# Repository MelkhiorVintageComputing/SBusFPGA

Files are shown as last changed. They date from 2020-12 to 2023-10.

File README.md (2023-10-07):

# A FPGA on a SBus card...

## Goal

The goal of this repository is to be able to interface a modern (2020 era) [FPGA](https://en.wikipedia.org/wiki/Field-programmable_gate_array) with a [SBus](https://en.wikipedia.org/wiki/SBus) host. SBus was widely used in SPARCstation and compatibles system in the first half of the 90s. It was progressively displaced by PCI from the mid-90s onward, and is thoroughly obsolete.

So unless you're a retrocomputing enthusiast with such a machine, this is useless. To be honest, even if you are such an enthusiast, it's probably not that useful...

I'm a software guy and know next to nothing about hardware design, so this is very much a work-in-progress and is likely full of rookie mistakes.

To save on PCB cost, the board is smaller than a 'true' SBus board; the hardware directory includes an OpenSCAD 3D-printable extension to make the board compliant to the form factor (visible in the pictures in 'Pictures') (need to be updated for V1.3).

## Current status

2023-10-07: V1.3 in testing.

2022-11-18: V1.2 seems stable, with various subsets of the peripherals described below. It only lacks a proper video output, such as the one available in the [NuBusFPGA](https://github.com/rdolbeau/NuBusFPGA). Unfortunately the FPGA board used in V1.0/V1.2 (ZTex 2.13) doesn't have enough available I/O to add it in addition to the already existing I/Os.

## The hardware

Directory 'sbus-to-ztex'

The V1.2 custom board is a SBus-compliant (I hope...) board, designed to receive a [ZTex USB-FPGA Module 2.13](https://www.ztex.de/usb-fpga-2/usb-fpga-2.13.e.html) as a daughterboard. The ZTex module contains the actual FPGA (Artix-7), some RAM, programming hardware, etc. The SBus board contains level-shifters ICs to interface between the SBus signals and the FPGA, a serial header, a Led, a JTAG header, a micro-sd card slot, a USB micro-B connector, and a (Pmod)[https://digilent.com/shop/boards-and-components/system-board-expansion-modules/pmods/] connector. It supports every SBus feature except the optional parity (i.e. it can do both slave and master modes) and interrupt level 1 to 6 are connected.

The V1.3 custom board is similar to V1.2 but reorganized & redesigned to have all components on the top side and cleaner routing. It also loose the led, setial header & micro-sd to gain a HDMI connector. The USB micro-B is still present, and the PMod was rewired to carry 8 length-matched differential pairs.

The PCB was designed with Kicad 5.0 for V1.2, 5.1 for V1.3.

## The gateware (Migen)

Directory 'sbus-to-ztex-gateware-migen'

### Intro

The gateware is written in the Migen language, choosen because that's what [Litex](https://github.com/enjoy-digital/litex/) uses.
It implements a simple CPU-less Litex SoC built around a Wishbone bus, with a custom bridge between the SBus and the Wishbone.

A ROM, a SDRAM controller ([litedram](https://github.com/enjoy-digital/litedram) to the on-board DDR3), a TRNG (using the [NeoRV32](https://github.com/stnolting/neorv32) TRNG), an USB OHCI (host controller, using the Litex wrapper around the [SpinalHDL](https://github.com/SpinalHDL/SpinalHDL) implementation), a Curve25519 Crypto Engine (taken from the [Betrusted.IO](https://betrusted.io/) project and expanded to add AES and GCM support) and a Litex micro-sd controller can be connected to that bus. As a test feature for the Pmod connector, a bw2/cg3/cg6-compatible framebuffer can be implemented using a custom RGA222 VGA Pmod (with serious color quality restrictions). The 'Goblin' framebuffer (a multi-depth gramebuffer) can also be used with the VGA Pmod, using 8-bits depth in the console or accelerated 24-bits in X11. Alternatively on the Pmod en I2C bus (the Betrusted.IO wrapper around an OpenCore controller) can be implemented for e.g. temperature control.

### Details

Master access to the SBus by the host are routed to the Wishbone to access the various CSRs / control registers of the devices.

The ROM exposes the devices' existence and specifications to the host, initializes the embedded SDRAM controller (but assuming known values, the NetBSD driver can also optionally initialize the SDRAM via proper calibration), enables FB support on the bw2/cg3/cg6 (last one with accelerated scrolling), and has support for RO access to the sdcard such enabling booting.

The USB OHCI DMA (USB 1.1) is bridged from the Wishbone to the SBus by having the physical addresses of the Wishbone (that match the virtual addresses from NetBSD DVMA allocations) to the bridge (see also 'Sun4m vs. Sun4c' below). Reads are buffered by block of 16 bytes; currently writes are unbuffered (and somewhat slow, as they need a full SBus master cycle for every transaction of 32 bits or less). The standard NetBSD OHCI driver is used, with just a small custom SBus-OHCI driver mirroring the PCI-OHCI one. It uses the interrupt level 4 by default. It connects to the micro-B USB connector, an a cable such as [this one](https://www.startech.com/en-us/cables/uusbotgra) allows to expose a conventional USB type A connector for either an external (preferably self-powered) USB Hub or a single low-power device.

The SDRAM has its own custom DMA controller, using native Litedram interface to the memory, and some FIFO to/from the SBus. A custom NetBSD driver exposes it as a drive on which you can swap. It's also usable as a 'fast', volatile disk (for e.g. /tmp or similar temporary filesystem). It can use a interrupt line, but software support isn't there yet (only synchronous polling).

The micro-sd card controller is using a similar driver to the SDRAM, so is also currently limited to sychronous polling and lack of support for interrupts (or removability). It also has some level of support in the PROM, enabling it as a boot device (of course using a NetBSD kernel with appropriate support). For its DMA engine, the micro-sd controller uses the same Wishbone/SBus bridge as designed for the USB OHCI.

The TRNG has a NetBSD driver to add entropy to the entropy pool.

The Curve25519 Engine currently exposes an IOCTL to do the computation, which has yet to be integrated usefully in e.g. OpenSSL. It could use a interrupt line, but it's not yet implemented in software. The load/store unit used the same Wishbone/SBus bridge as designed for the USB OHCI.

The I2C bus currently uses a custom Pmod to plug an AT30TS74 temperature sensor (LM75-compatible, usable with 'envstat' in NetBSD), but should support most/all I2C devices supported by NetBSD.

The bw2/cg3/cg6 emulation requires the custom Pmod on V1.2, and colors are vert limited at 2 bits per channel, so it's for testing mostly. V1.3 has a HDMI connector using DVI signaling and so support the full color range. bw2/cg3 can work as a PROM console, a NetBSD console, and with X11, all as an non-accelerated framebuffer. Resolution can be arbitrary but is fixed in the bitstream at synthesis time, the current design can go up to 1920x1080@60Hz. cg6 emulation is similar but uses a micro-coded VexRiscv core to emulate some of the cg6 hardware acceleration, enough to accelerate the PROM console, the NetBSD console and X11 EXA acceleration in NetBSD 9.0. The cg3/cg6 emulation was also tested with the original PROM code for cg3 (501-1415) and TGX+ (501-2253), but this requires hardware-based initialization (instead of PROM-based) and prevent exposing other devices in the PROM code.

The 'Goblin' framebuffer works similarly to the cg6 emulation (from which it has grown for the NuBusFPGA), but is using 24-bits in X11 (switching in a way similar to the cg14) and has some Xrender acceleration. Using the same 2-bits-per-channel VGA Pmod, it also suffers from color limitations ob V1.2. It also uses tje HDMI connector on V1.3.

### Special Notes

Currently the design uses a Wishbone Crossbar Interconnect from Litex instead of a Shared Interconnect, as for some reason using a Shared Interconnect causes issues between devices (disabling the USB OHCI seem also to solve the issue, it generates a lot of cycles on the buses). I might be misusing Wishbone. With the Crossbar, all devices are usable simultaneously if they fit in the FPGA.

As not everything lives in the same clock domain, the design also use a Wishbone CDC, a wrapper around the one from [Verilog Wishbone Components](https://github.com/alexforencich/verilog-wishbone).

## The software

Directory 'NetBSD'

Some basic drivers for NetBSD 9.0/sparc to enable the devices as described above. bw2/cg3/cg6 uses unmodifed NetBSD drivers. USB OHCI needs only a SBus-OHCI layer, the NetBSD OHCI driver and USB stack are used unmodified.

## Sun4m vs. Sun4c

The current DMA scheme for Wishbone devices (USB OHCI, micro-sd, ...) works fine on sun4m machine with an IOMMU (SPARCstation 4, 5, 10, 20 ...). NetBSD will always allocate the DVMA buffers in the range from IOMMU_DVMA_BASE to the end of the memory space (IOMMU_DVMA_BASE is 0xFC000000 by default, and that must include 0xFF000000 to the end which are the only virtual addresses accessible by some legacy devices used in some SPARCstation). However, sun4c machine (SPARCstation 1, 2, IPC, IPX, ...) do not have an IOMMU, and have no virtual address restriction for non-legacy device. And the NetBSD kernel takes advantage of this, I have observed DVMA buffers mapped to prefix 0xF4 and 0xF3. Extending the mapping for the DVMA bridge in Wishbone to the full 0xF prefix enable booting from sd-card on an IPX, but I'm not sure this is reliable.

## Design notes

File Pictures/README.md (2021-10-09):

## Some picture of the V1.0 and V1.2 boards

This is V1.2:
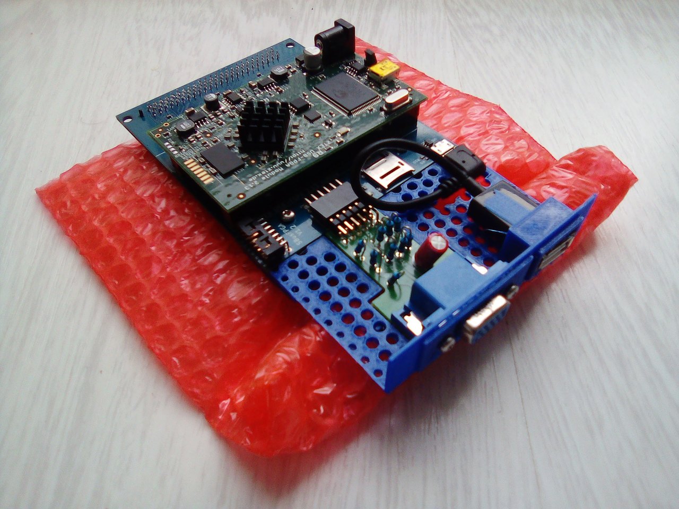
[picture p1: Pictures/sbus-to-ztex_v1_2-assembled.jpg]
Picture of the V1.2 board with cables


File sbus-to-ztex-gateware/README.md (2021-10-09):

## Current status

2021-03-21: The adapter board seems to work fine in two different SS20. Currently the embedded PROM code exposes three devices in the FPGA:

* "RDOL,cryptoengine": exposes a (way too large) polynomial multiplier to implement GCM mode and a AES block. Currently used to implement DMA-based acceleration of AES-256-CBC through /dev/crypto. Unfortunately OpenSSL doesn't support AES-256-GCM in the cryptodev engine, and disagree with NetBSD's /dev/crypto on how to implement AES-256-CTR. And the default SSH cannot use cryptodev, it closes all file descriptors after cryptodev has opened /dev/crypto... still WiP.

* "RDOL,trng": exposes a 5 MHz counter (didn't realize the SS20 already had a good counter) and a so-far-not-true TRNG (implemented by a PRNG). The 'true' random generators I've found make Vivado screams very loudly when synthesizing... anyway both works fine in NetBSD 9.0 as a timecounter and an entropy source (which a PRNG really isn't, I know).  still WiP.

* "RDOL,sdcard": trying to expose the micro-sd card slot as a storage device, at first using SPI mode. So far reading seems to work, and NetBSD can see a Sun disklabel on the micro-sd card if it has been partitioned that way. Mounting a FAT filesystem read-only now works (with very little testing as of yet). Writing not working yet. Very much WiP.

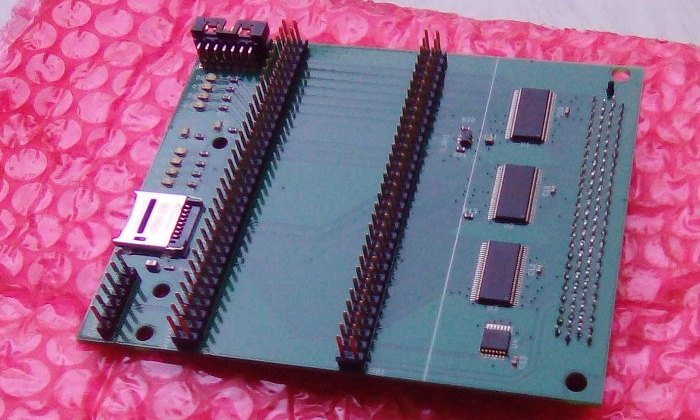
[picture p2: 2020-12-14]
Pictures/sbus-to-ztex.jpg

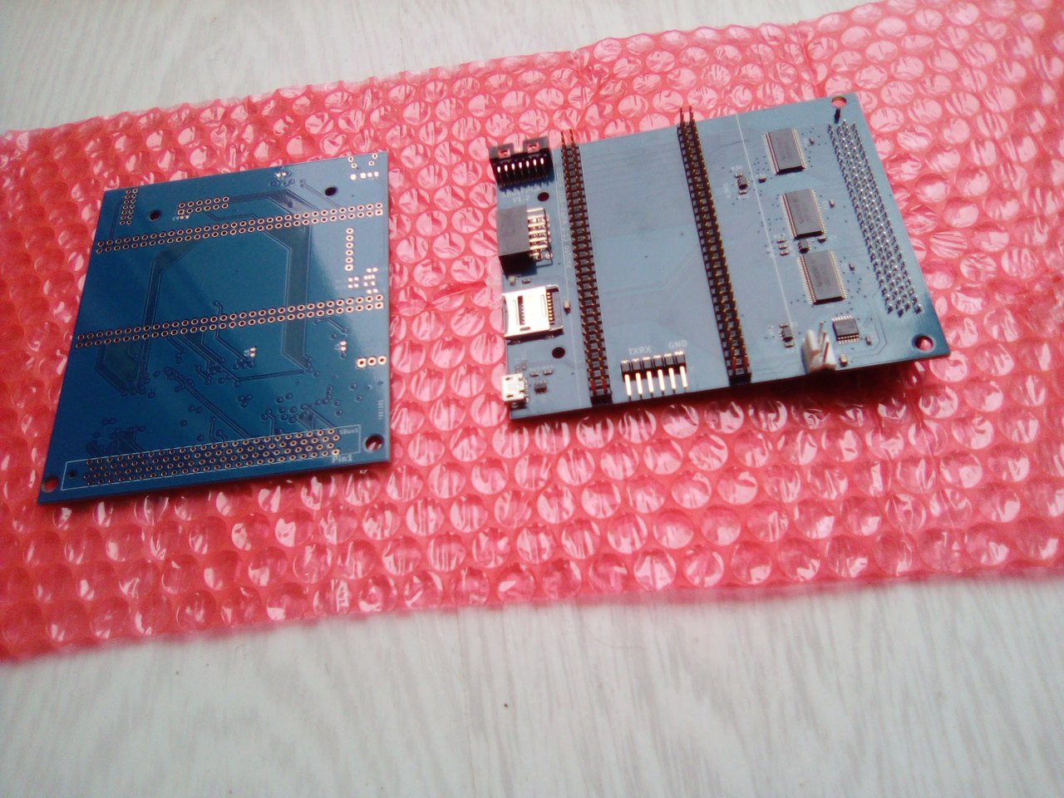
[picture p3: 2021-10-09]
Pictures/sbus-to-ztex_v1_2.jpg

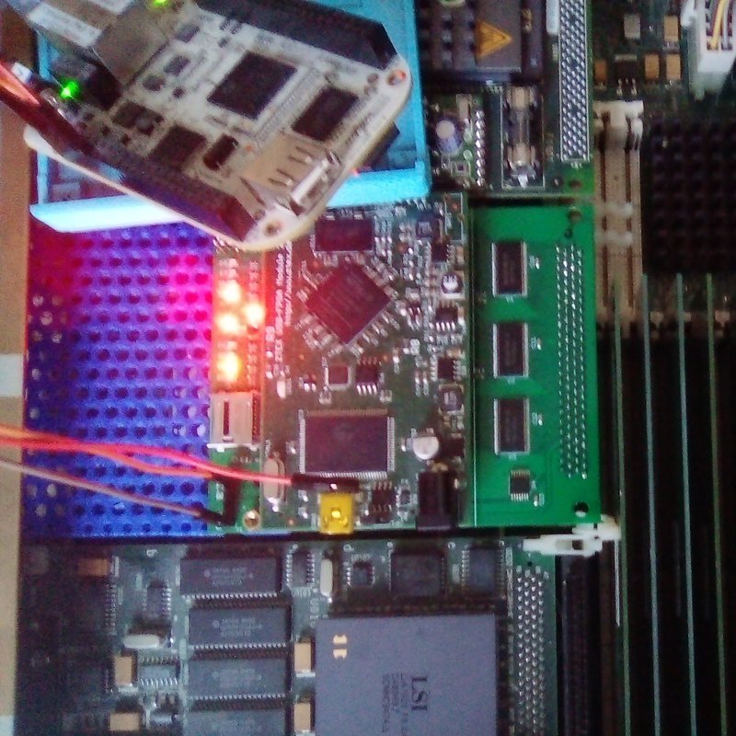
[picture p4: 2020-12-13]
Pictures/sbus-to-ztex-in-SS20.jpg

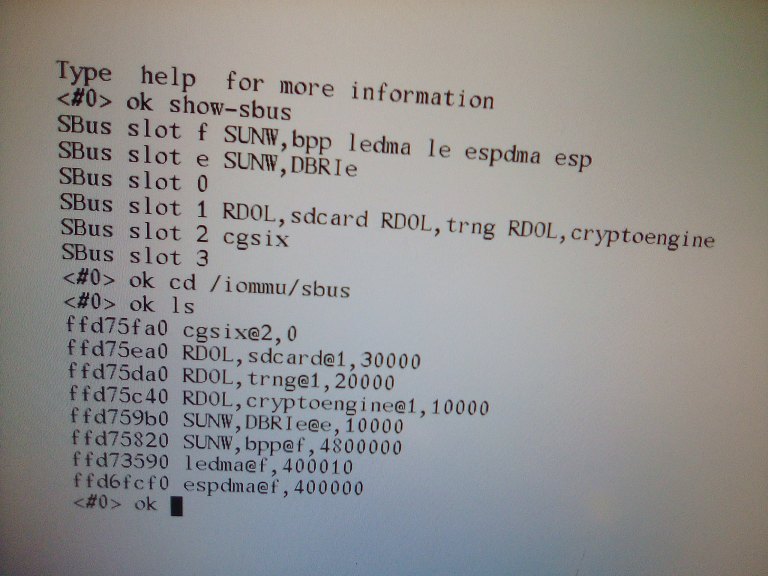
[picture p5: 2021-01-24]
Pictures/sbus-to-ztex-prom.jpg

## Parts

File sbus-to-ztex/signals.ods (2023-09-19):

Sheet: length
signal | pin (FPGA) | pin (board) | Ztex 2.13 | Current | Total | Missing | Should be
HDMI_D2+ |  | D04 | 47,25 | 26,005 | 73,255 | 0 | 26,005
HDMI_D2- |  | D05 | 44,17 | 29,085 | 73,255 | 0 | 29,085
HDMI_D1+ |  | D06 | 47,7 | 25,555 | 73,255 | 0 | 25,555
HDMI_D1- |  | D07 | 40,07 | 33,185 | 73,255 | 0 | 33,185
HDMI_D0+ |  | D08 | 43,24 | 30,015 | 73,255 | 0 | 30,015
HDMI_D0- |  | D09 | 36,91 | 36,345 | 73,255 | 0 | 36,345
HDMI_CLK+ |  | D10 | 36,12 | 37,135 | 73,255 | 0 | 37,135
HDMI_CLK- |  | D11 | 31,28 | 41,975 | 73,255 | 0 | 41,975
 |  |  |  |  | 73,255
PMOD-1112+ |  | D21 | 14,73 | 20,876 | 35,606 | 0 | 20,876 | -1,11
PMOD-1112- |  | D22 | 13,62 | 21,986 | 35,606 | 0 | 21,986
PMOD-910- |  | D23 | 11,52 | 24,086 | 35,606 | 0 | 24,086 | 1,39
PMOD-910+ |  | D24 | 12,91 | 22,696 | 35,606 | 0 | 22,696
PMOD-78- |  | D25 | 14,18 | 21,426 | 35,606 | 0 | 21,426 | 1,788
PMOD-78+ |  | D26 | 15,93 | 19,638 | 35,568 | 0,038000000000004 | 19,676
PMOD-56+ |  | D27 | 17,29 | 18,316 | 35,606 | 0 | 18,316 | 1,06
PMOD-56- |  | D28 | 18,35 | 17,256 | 35,606 | 0 | 17,256
 |  |  |  |  | 35,606

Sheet: 2.13 pin -> trace length
A03 | 47,94
A04 | 50,82
A05 | 49,92
A06 | 46,16
A07 | 41,01
A08 | 36,34
A09 | 35,18
A10 | 31,47
A11 | 29,79
A12 | 28,44
A13 | 25,47
A14 | 33,51
A18 | 19,12
A19 | 16,11
A20 | 12,52
A21 | 11,42
A22 | 16,17
A23 | 12,65
A24 | 16,68
A25 | 18,84
A26 | 14,67
A27 | 17,14
A28 | 22,76
A29 | 23,12
A30 | 26,67
B03 | 47,46
B04 | 43,6
B05 | 50,53
B06 | 43,56
B07 | 41,18
B08 | 38,13
B09 | 33,55
B10 | 30,82
B11 | 42,85
B12 | 26,76
B13 | 23,54
B14 | 21,66
B18 | 12,94
B19 | 10,5
B20 | 7,79
B21 | 4,99
B22 | 7,67
B23 | 6,56
B24 | 9,37
B25 | 11,32
B26 | 10,64
B27 | 14,66
B28 | 16,13
B29 | 18,45
B30 | 19,53
C03 | 48,06
C04 | 50,42
C05 | 44,03
C06 | 40,65
C07 | 40,55
C08 | 36,89
C09 | 42,83
C10 | 40,83
C11 | 29,53
C12 | 28,85
C13 | 23,26
C14 | 22,23
C15 | 29,19
C19 | 15,66
C20 | 13,54
C21 | 13,92
C22 | 10,82
C23 | 8,85
C24 | 10,26
C25 | 10,34
C26 | 10,91
C27 | 15,81
C28 | 16,75
C29 | 18,52
C30 | 20,19
D03 | 48,26
D04 | 47,25
D05 | 44,17
D06 | 47,7
D07 | 40,07
D08 | 43,24
D09 | 36,91
D10 | 36,12
D11 | 31,28
D12 | 28,32
D13 | 27,1
D14 | 24,45
D15 | 23,76
D19 | 19,51
D20 | 17,59
D21 | 14,73
D22 | 13,62
D23 | 11,52
D24 | 12,91
D25 | 14,18
D26 | 15,93
D27 | 17,29
D28 | 18,35
D29 | 20,28
D30 | 22,14

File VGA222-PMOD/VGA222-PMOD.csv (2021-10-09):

Part/Designator | Manufacture Part Number/Seeed SKU | Quantity | URL
C3 | 860021373002 | 1
J2 | A2541WR-2x6P | 1
J1 | L77HDE15SD1CH4RHNVGA | 1 | https://www.mouser.fr/ProductDetail/Amphenol-Commercial-Products/L77HDE15SD1CH4RHNVGA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
R10,R11 | MFR-25FBF52-100R | 2
R13,R19,R25 | MFR-25FBF52-1K | 3
R12,R18,R24 | MFR-25FTE52-510R | 3
R9 | MFR50SFTE52-1M | 1 | https://www.lcsc.com/product-detail/Chip-Resistor-Surface-Mount_UNI-ROYAL-Uniroyal-Elec-AS03W4J0105T5E_C966202.html

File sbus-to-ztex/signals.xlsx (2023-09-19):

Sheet: Summary
Connector PIN | USB-FPGA-Module 2.13 |  |  |  |  |  |  |  |  |  |  |  |  |  |  |  |  |  |  |  |  |  |  | LITEX def
 | Signal | I/O Voltage | FPGA PIN | CPLD PIN | Notes | Number |  | Used Pin | Signal | 2.13 trace length (mm) | added length |  |  |  |  |  |  | XDC PIN | XDC TIMING IN | DXC TIMING OUT |  | https://forums.xilinx.com/t5/Timing-Analysis/Significance-of-set-output-delay-max-min-negative-and-positive/td-p/779277
A1 | VIN |  |  |  | 4.5..16V | 1 | #N/A
B1 | VIN |  |  |  | 4.5..16V | 2 | #N/A |  |  |  |  |  |  |  |  |  |  | TIS (min) | 15 | 20 | TOD (max) | 22.5 in B0
A2 | GND |  |  |  |  | 3 | #N/A |  |  |  |  |  |  |  |  |  | 0 in B0 | TIH (min) | 1 | 2.5 | TOH (min) |  | 0.6304662693
B2 | GND |  |  |  |  | 4 | #N/A |  |  |  |  |  |  |  |  |  |  |  | mm/ns (fast so MIN) | mm/ns (slow so MAX) |  |  | 0.2218339054
 |  |  |  |  |  |  | #N/A |  |  |  |  |  |  |  |  |  |  |  | 200 | 150
A3 | K16~IO_25_15 | VCCO_AB | K16 |  |  | 5 | SBUS_3V3_BR* | K16~IO_25_15 | SBUS_3V3_BR* | 47.94 | 78.15 |  | 126.09 | 4.96 |  | -81.73 | IO | set_property PACKAGE_PIN K16 [get_ports {SBUS_3V3_BR*}] set_property IOSTANDARD LVTTL [get_ports {SBUS_3V3_BR*}] | set_input_delay -clock SBUS_3V3_CLK -min 1,159 [get_ports {SBUS_3V3_BR*}] set_input_delay -clock SBUS_3V3_CLK -max 25,795 [get_ports {SBUS_3V3_BR*}] | set_output_delay -clock SBUS_3V3_CLK -min -1,648 [get_ports {SBUS_3V3_BR*}] set_output_delay -clock SBUS_3V3_CLK -max 21,636 [get_ports {SBUS_3V3_BR*}] |  | set_input_delay -clock SBUS_3V3_CLK -min 1,159 [get_ports {SBUS_3V3_BR*}] set_input_delay -clock SBUS_3V3_CLK -max 25,795 [get_ports {SBUS_3V3_BR*}] set_output_delay -clock SBUS_3V3_CLK -min -1,648 [get_ports {SBUS_3V3_BR*}] set_output_delay -clock SBUS_3V3_CLK -max 21,636 [get_ports {SBUS_3V3_BR*}]
B3 | J18~IO_L23N_T3_FWE_B_15 | VCCO_AB | J18 |  |  | 6 | I2C0_SDA | J18~IO_L23N_T3_FWE_B_15 | I2C0_SDA | 47.46 | #N/A |  | #N/A | #N/A |  | #N/A | IO | set_property PACKAGE_PIN J18 [get_ports {I2C0_SDA}] set_property IOSTANDARD LVTTL [get_ports {I2C0_SDA}]
A4 | K15~IO_L24P_T3_RS1_15 | VCCO_AB | K15 |  |  | 7 | SBUS_3V3_BG* | K15~IO_L24P_T3_RS1_15 | SBUS_3V3_BG* | 50.82 | 77.84 |  | 128.66 | 5.07 |  | -84.29 | IO | set_property PACKAGE_PIN K15 [get_ports {SBUS_3V3_BG*}] set_property IOSTANDARD LVTTL [get_ports {SBUS_3V3_BG*}] | set_input_delay -clock SBUS_3V3_CLK -min 1,171 [get_ports {SBUS_3V3_BG*}] set_input_delay -clock SBUS_3V3_CLK -max 25,812 [get_ports {SBUS_3V3_BG*}] | set_output_delay -clock SBUS_3V3_CLK -min -1,635 [get_ports {SBUS_3V3_BG*}] set_output_delay -clock SBUS_3V3_CLK -max 21,654 [get_ports {SBUS_3V3_BG*}] |  | set_input_delay -clock SBUS_3V3_CLK -min 1,171 [get_ports {SBUS_3V3_BG*}] set_input_delay -clock SBUS_3V3_CLK -max 25,812 [get_ports {SBUS_3V3_BG*}] set_output_delay -clock SBUS_3V3_CLK -min -1,635 [get_ports {SBUS_3V3_BG*}] set_output_delay -clock SBUS_3V3_CLK -max 21,654 [get_ports {SBUS_3V3_BG*}]
B4 | J17~IO_L23P_T3_FOE_B_15 | VCCO_AB | J17 |  |  | 8 | I2C0_SCL | J17~IO_L23P_T3_FOE_B_15 | I2C0_SCL | 43.6 | #N/A |  | #N/A | #N/A |  | #N/A | IO | set_property PACKAGE_PIN J17 [get_ports {I2C0_SCL}] set_property IOSTANDARD LVTTL [get_ports {I2C0_SCL}]
A5 | J15~IO_L24N_T3_RS0_15 | VCCO_AB | J15 |  |  | 9 | SBUS_3V3_AS* | J15~IO_L24N_T3_RS0_15 | SBUS_3V3_AS* | 49.92 | 67.60 |  | 117.52 | 4.63 |  | -73.15 | IO | set_property PACKAGE_PIN J15 [get_ports {SBUS_3V3_AS*}] set_property IOSTANDARD LVTTL [get_ports {SBUS_3V3_AS*}] | set_input_delay -clock SBUS_3V3_CLK -min 1,116 [get_ports {SBUS_3V3_AS*}] set_input_delay -clock SBUS_3V3_CLK -max 25,738 [get_ports {SBUS_3V3_AS*}] | set_output_delay -clock SBUS_3V3_CLK -min -1,691 [get_ports {SBUS_3V3_AS*}] set_output_delay -clock SBUS_3V3_CLK -max 21,579 [get_ports {SBUS_3V3_AS*}] |  | set_input_delay -clock SBUS_3V3_CLK -min 1,116 [get_ports {SBUS_3V3_AS*}] set_input_delay -clock SBUS_3V3_CLK -max 25,738 [get_ports {SBUS_3V3_AS*}] set_output_delay -clock SBUS_3V3_CLK -min -1,691 [get_ports {SBUS_3V3_AS*}] set_output_delay -clock SBUS_3V3_CLK -max 21,579 [get_ports {SBUS_3V3_AS*}]
B5 | K13~IO_L17P_T2_A26_15 | VCCO_AB | K13 |  |  | 10 | SBUS_OE | K13~IO_L17P_T2_A26_15 | SBUS_OE | 50.53 | #N/A |  | #N/A | #N/A |  | #N/A | IO | set_property PACKAGE_PIN K13 [get_ports {SBUS_OE}] set_property IOSTANDARD LVTTL [get_ports {SBUS_OE}]
A6 | H15~IO_L19N_T3_A21_VREF_15 | VCCO_AB | H15 |  | VREF Bank 15 | 11 | SBUS_3V3_SEL* | H15~IO_L19N_T3_A21_VREF_15 | SBUS_3V3_SEL* | 46.16 | 74.37 |  | 120.53 | 4.75 |  | -76.16 | O | set_property PACKAGE_PIN H15 [get_ports {SBUS_3V3_SEL*}] set_property IOSTANDARD LVTTL [get_ports {SBUS_3V3_SEL*}] | set_input_delay -clock SBUS_3V3_CLK -min 1,131 [get_ports {SBUS_3V3_SEL*}] set_input_delay -clock SBUS_3V3_CLK -max 25,758 [get_ports {SBUS_3V3_SEL*}] | set_output_delay -clock SBUS_3V3_CLK -min -1,676 [get_ports {SBUS_3V3_SEL*}] set_output_delay -clock SBUS_3V3_CLK -max 21,599 [get_ports {SBUS_3V3_SEL*}] |  | set_output_delay -clock SBUS_3V3_CLK -min -1,676 [get_ports {SBUS_3V3_SEL*}] set_output_delay -clock SBUS_3V3_CLK -max 21,599 [get_ports {SBUS_3V3_SEL*}]
B6 | J13~IO_L17N_T2_A25_15 | VCCO_AB | J13 |  |  | 12 | SBUS_3V3_D[00] | J13~IO_L17N_T2_A25_15 | SBUS_3V3_D[00] | 43.56 | 44.69 |  | 88.25 | 3.47 |  | -43.88 | IO | set_property PACKAGE_PIN J13 [get_ports {SBUS_3V3_D[00]}] set_property IOSTANDARD LVTTL [get_ports {SBUS_3V3_D[00]}] | set_input_delay -clock SBUS_3V3_CLK -min 0,969 [get_ports {SBUS_3V3_D[00]}] set_input_delay -clock SBUS_3V3_CLK -max 25,543 [get_ports {SBUS_3V3_D[00]}] | set_output_delay -clock SBUS_3V3_CLK -min -1,837 [get_ports {SBUS_3V3_D[00]}] set_output_delay -clock SBUS_3V3_CLK -max 21,384 [get_ports {SBUS_3V3_D[00]}] |  | set_input_delay -clock SBUS_3V3_CLK -min 0,969 [get_ports {SBUS_3V3_D[00]}] set_input_delay -clock SBUS_3V3_CLK -max 25,543 [get_ports {SBUS_3V3_D[00]}] set_output_delay -clock SBUS_3V3_CLK -min -1,837 [get_ports {SBUS_3V3_D[00]}] set_output_delay -clock SBUS_3V3_CLK -max 21,384 [get_ports {SBUS_3V3_D[00]}]
A7 | J14~IO_L19P_T3_A22_15 | VCCO_AB | J14 |  |  | 13 | SBUS_3V3_D[02] | J14~IO_L19P_T3_A22_15 | SBUS_3V3_D[02] | 41.01 | 41.44 |  | 82.45 | 3.25 |  | -38.08 | IO | set_property PACKAGE_PIN J14 [get_ports {SBUS_3V3_D[02]}] set_property IOSTANDARD LVTTL [get_ports {SBUS_3V3_D[02]}] | set_input_delay -clock SBUS_3V3_CLK -min 0,940 [get_ports {SBUS_3V3_D[02]}] set_input_delay -clock SBUS_3V3_CLK -max 25,504 [get_ports {SBUS_3V3_D[02]}] | set_output_delay -clock SBUS_3V3_CLK -min -1,866 [get_ports {SBUS_3V3_D[02]}] set_output_delay -clock SBUS_3V3_CLK -max 21,345 [get_ports {SBUS_3V3_D[02]}] |  | set_input_delay -clock SBUS_3V3_CLK -min 0,940 [get_ports {SBUS_3V3_D[02]}] set_input_delay -clock SBUS_3V3_CLK -max 25,504 [get_ports {SBUS_3V3_D[02]}] set_output_delay -clock SBUS_3V3_CLK -min -1,866 [get_ports {SBUS_3V3_D[02]}] set_output_delay -clock SBUS_3V3_CLK -max 21,345 [get_ports {SBUS_3V3_D[02]}]
B7 | H14~IO_L15P_T2_DQS_15 | VCCO_AB | H14 |  |  | 14 | SBUS_3V3_D[03] | H14~IO_L15P_T2_DQS_15 | SBUS_3V3_D[03] | 41.18 | 34.67 |  | 75.85 | 2.99 |  | -31.49 | IO | set_property PACKAGE_PIN H14 [get_ports {SBUS_3V3_D[03]}] set_property IOSTANDARD LVTTL [get_ports {SBUS_3V3_D[03]}] | set_input_delay -clock SBUS_3V3_CLK -min 0,907 [get_ports {SBUS_3V3_D[03]}] set_input_delay -clock SBUS_3V3_CLK -max 25,460 [get_ports {SBUS_3V3_D[03]}] | set_output_delay -clock SBUS_3V3_CLK -min -1,899 [get_ports {SBUS_3V3_D[03]}] set_output_delay -clock SBUS_3V3_CLK -max 21,301 [get_ports {SBUS_3V3_D[03]}] |  | set_input_delay -clock SBUS_3V3_CLK -min 0,907 [get_ports {SBUS_3V3_D[03]}] set_input_delay -clock SBUS_3V3_CLK -max 25,460 [get_ports {SBUS_3V3_D[03]}] set_output_delay -clock SBUS_3V3_CLK -min -1,899 [get_ports {SBUS_3V3_D[03]}] set_output_delay -clock SBUS_3V3_CLK -max 21,301 [get_ports {SBUS_3V3_D[03]}]
A8 | H17~IO_L18P_T2_A24_15 | VCCO_AB | H17 |  |  | 15 | SBUS_3V3_D[05] | H17~IO_L18P_T2_A24_15 | SBUS_3V3_D[05] | 36.34 | 35.94 |  | 72.28 | 2.85 |  | -27.91 | IO | set_property PACKAGE_PIN H17 [get_ports {SBUS_3V3_D[05]}] set_property IOSTANDARD LVTTL [get_ports {SBUS_3V3_D[05]}] | set_input_delay -clock SBUS_3V3_CLK -min 0,890 [get_ports {SBUS_3V3_D[05]}] set_input_delay -clock SBUS_3V3_CLK -max 25,436 [get_ports {SBUS_3V3_D[05]}] | set_output_delay -clock SBUS_3V3_CLK -min -1,917 [get_ports {SBUS_3V3_D[05]}] set_output_delay -clock SBUS_3V3_CLK -max 21,278 [get_ports {SBUS_3V3_D[05]}] |  | set_input_delay -clock SBUS_3V3_CLK -min 0,890 [get_ports {SBUS_3V3_D[05]}] set_input_delay -clock SBUS_3V3_CLK -max 25,436 [get_ports {SBUS_3V3_D[05]}] set_output_delay -clock SBUS_3V3_CLK -min -1,917 [get_ports {SBUS_3V3_D[05]}] set_output_delay -clock SBUS_3V3_CLK -max 21,278 [get_ports {SBUS_3V3_D[05]}]
B8 | G14~IO_L15N_T2_DQS_ADV_B_15 | VCCO_AB | G14 |  |  | 16 | SBUS_3V3_D[06] | G14~IO_L15N_T2_DQS_ADV_B_15 | SBUS_3V3_D[06] | 38.13 | 41.66 |  | 79.79 | 3.14 |  | -35.43 | IO | set_property PACKAGE_PIN G14 [get_ports {SBUS_3V3_D[06]}] set_property IOSTANDARD LVTTL [get_ports {SBUS_3V3_D[06]}] | set_input_delay -clock SBUS_3V3_CLK -min 0,927 [get_ports {SBUS_3V3_D[06]}] set_input_delay -clock SBUS_3V3_CLK -max 25,486 [get_ports {SBUS_3V3_D[06]}] | set_output_delay -clock SBUS_3V3_CLK -min -1,879 [get_ports {SBUS_3V3_D[06]}] set_output_delay -clock SBUS_3V3_CLK -max 21,328 [get_ports {SBUS_3V3_D[06]}] |  | set_input_delay -clock SBUS_3V3_CLK -min 0,927 [get_ports {SBUS_3V3_D[06]}] set_input_delay -clock SBUS_3V3_CLK -max 25,486 [get_ports {SBUS_3V3_D[06]}] set_output_delay -clock SBUS_3V3_CLK -min -1,879 [get_ports {SBUS_3V3_D[06]}] set_output_delay -clock SBUS_3V3_CLK -max 21,328 [get_ports {SBUS_3V3_D[06]}]
A9 | G17~IO_L18N_T2_A23_15 | VCCO_AB | G17 |  |  | 17 | SBUS_3V3_D[08] | G17~IO_L18N_T2_A23_15 | SBUS_3V3_D[08] | 35.18 | 38.25 |  | 73.43 | 2.89 |  | -29.06 | IO | set_property PACKAGE_PIN G17 [get_ports {SBUS_3V3_D[08]}] set_property IOSTANDARD LVTTL [get_ports {SBUS_3V3_D[08]}] | set_input_delay -clock SBUS_3V3_CLK -min 0,895 [get_ports {SBUS_3V3_D[08]}] set_input_delay -clock SBUS_3V3_CLK -max 25,444 [get_ports {SBUS_3V3_D[08]}] | set_output_delay -clock SBUS_3V3_CLK -min -1,911 [get_ports {SBUS_3V3_D[08]}] set_output_delay -clock SBUS_3V3_CLK -max 21,285 [get_ports {SBUS_3V3_D[08]}] |  | set_input_delay -clock SBUS_3V3_CLK -min 0,895 [get_ports {SBUS_3V3_D[08]}] set_input_delay -clock SBUS_3V3_CLK -max 25,444 [get_ports {SBUS_3V3_D[08]}] set_output_delay -clock SBUS_3V3_CLK -min -1,911 [get_ports {SBUS_3V3_D[08]}] set_output_delay -clock SBUS_3V3_CLK -max 21,285 [get_ports {SBUS_3V3_D[08]}]
B9 | G16~IO_L13N_T2_MRCC_15 | VCCO_AB | G16 |  | MRCC | 18 | SBUS_3V3_D[09] | G16~IO_L13N_T2_MRCC_15 | SBUS_3V3_D[09] | 33.55 | 31.26 |  | 64.81 | 2.55 |  | -20.44 | IO | set_property PACKAGE_PIN G16 [get_ports {SBUS_3V3_D[09]}] set_property IOSTANDARD LVTTL [get_ports {SBUS_3V3_D[09]}] | set_input_delay -clock SBUS_3V3_CLK -min 0,852 [get_ports {SBUS_3V3_D[09]}] set_input_delay -clock SBUS_3V3_CLK -max 25,386 [get_ports {SBUS_3V3_D[09]}] | set_output_delay -clock SBUS_3V3_CLK -min -1,954 [get_ports {SBUS_3V3_D[09]}] set_output_delay -clock SBUS_3V3_CLK -max 21,228 [get_ports {SBUS_3V3_D[09]}] |  | set_input_delay -clock SBUS_3V3_CLK -min 0,852 [get_ports {SBUS_3V3_D[09]}] set_input_delay -clock SBUS_3V3_CLK -max 25,386 [get_ports {SBUS_3V3_D[09]}] set_output_delay -clock SBUS_3V3_CLK -min -1,954 [get_ports {SBUS_3V3_D[09]}] set_output_delay -clock SBUS_3V3_CLK -max 21,228 [get_ports {SBUS_3V3_D[09]}]
A10 | G18~IO_L22P_T3_A17_15 | VCCO_AB | G18 |  |  | 19 | SBUS_3V3_D[11] | G18~IO_L22P_T3_A17_15 | SBUS_3V3_D[11] | 31.47 | 33.45 |  | 64.92 | 2.56 |  | -20.55 | IO | set_property PACKAGE_PIN G18 [get_ports {SBUS_3V3_D[11]}] set_property IOSTANDARD LVTTL [get_ports {SBUS_3V3_D[11]}] | set_input_delay -clock SBUS_3V3_CLK -min 0,853 [get_ports {SBUS_3V3_D[11]}] set_input_delay -clock SBUS_3V3_CLK -max 25,387 [get_ports {SBUS_3V3_D[11]}] | set_output_delay -clock SBUS_3V3_CLK -min -1,954 [get_ports {SBUS_3V3_D[11]}] set_output_delay -clock SBUS_3V3_CLK -max 21,229 [get_ports {SBUS_3V3_D[11]}] |  | set_input_delay -clock SBUS_3V3_CLK -min 0,853 [get_ports {SBUS_3V3_D[11]}] set_input_delay -clock SBUS_3V3_CLK -max 25,387 [get_ports {SBUS_3V3_D[11]}] set_output_delay -clock SBUS_3V3_CLK -min -1,954 [get_ports {SBUS_3V3_D[11]}] set_output_delay -clock SBUS_3V3_CLK -max 21,229 [get_ports {SBUS_3V3_D[11]}]
B10 | H16~IO_L13P_T2_MRCC_15 | VCCO_AB | H16 |  | MRCC | 20 | SBUS_3V3_CLK | H16~IO_L13P_T2_MRCC_15 | SBUS_3V3_CLK | 30.82 | 59.72 |  | 90.54 | 3.56 |  | -46.17 | IO | set_property PACKAGE_PIN H16 [get_ports {SBUS_3V3_CLK}] set_property IOSTANDARD LVTTL [get_ports {SBUS_3V3_CLK}] | set_input_delay -clock SBUS_3V3_CLK -min 0,981 [get_ports {SBUS_3V3_CLK}] set_input_delay -clock SBUS_3V3_CLK -max 25,558 [get_ports {SBUS_3V3_CLK}] | set_output_delay -clock SBUS_3V3_CLK -min -1,825 [get_ports {SBUS_3V3_CLK}] set_output_delay -clock SBUS_3V3_CLK -max 21,399 [get_ports {SBUS_3V3_CLK}] |  | set_input_delay -clock SBUS_3V3_CLK -min 0,981 [get_ports {SBUS_3V3_CLK}] set_input_delay -clock SBUS_3V3_CLK -max 25,558 [get_ports {SBUS_3V3_CLK}] set_output_delay -clock SBUS_3V3_CLK -min -1,825 [get_ports {SBUS_3V3_CLK}] set_output_delay -clock SBUS_3V3_CLK -max 21,399 [get_ports {SBUS_3V3_CLK}]
A11 | F18~IO_L22N_T3_A16_15 | VCCO_AB | F18 |  |  | 21 | SBUS_3V3_D[14] | F18~IO_L22N_T3_A16_15 | SBUS_3V3_D[14] | 29.79 | 36.51 |  | 66.30 | 2.61 |  | -21.94 | IO | set_property PACKAGE_PIN F18 [get_ports {SBUS_3V3_D[14]}] set_property IOSTANDARD LVTTL [get_ports {SBUS_3V3_D[14]}] | set_input_delay -clock SBUS_3V3_CLK -min 0,860 [get_ports {SBUS_3V3_D[14]}] set_input_delay -clock SBUS_3V3_CLK -max 25,396 [get_ports {SBUS_3V3_D[14]}] | set_output_delay -clock SBUS_3V3_CLK -min -1,947 [get_ports {SBUS_3V3_D[14]}] set_output_delay -clock SBUS_3V3_CLK -max 21,238 [get_ports {SBUS_3V3_D[14]}] |  | set_input_delay -clock SBUS_3V3_CLK -min 0,860 [get_ports {SBUS_3V3_D[14]}] set_input_delay -clock SBUS_3V3_CLK -max 25,396 [get_ports {SBUS_3V3_D[14]}] set_output_delay -clock SBUS_3V3_CLK -min -1,947 [get_ports {SBUS_3V3_D[14]}] set_output_delay -clock SBUS_3V3_CLK -max 21,238 [get_ports {SBUS_3V3_D[14]}]
B11 | F16~IO_L14N_T2_SRCC_15 | VCCO_AB | F16 |  | SRCC | 22 | SBUS_3V3_D[15] | F16~IO_L14N_T2_SRCC_15 | SBUS_3V3_D[15] | 42.85 | 29.11 |  | 71.96 | 2.83 |  | -27.59 | IO | set_property PACKAGE_PIN F16 [get_ports {SBUS_3V3_D[15]}] set_property IOSTANDARD LVTTL [get_ports {SBUS_3V3_D[15]}] | set_input_delay -clock SBUS_3V3_CLK -min 0,888 [get_ports {SBUS_3V3_D[15]}] set_input_delay -clock SBUS_3V3_CLK -max 25,434 [get_ports {SBUS_3V3_D[15]}] | set_output_delay -clock SBUS_3V3_CLK -min -1,918 [get_ports {SBUS_3V3_D[15]}] set_output_delay -clock SBUS_3V3_CLK -max 21,275 [get_ports {SBUS_3V3_D[15]}] |  | set_input_delay -clock SBUS_3V3_CLK -min 0,888 [get_ports {SBUS_3V3_D[15]}] set_input_delay -clock SBUS_3V3_CLK -max 25,434 [get_ports {SBUS_3V3_D[15]}] set_output_delay -clock SBUS_3V3_CLK -min -1,918 [get_ports {SBUS_3V3_D[15]}] set_output_delay -clock SBUS_3V3_CLK -max 21,275 [get_ports {SBUS_3V3_D[15]}]
A12 | E18~IO_L21P_T3_DQS_15 | VCCO_AB | E18 |  |  | 23 | SBUS_3V3_D[17] | E18~IO_L21P_T3_DQS_15 | SBUS_3V3_D[17] | 28.44 | 30.26 |  | 58.70 | 2.31 |  | -14.34 | IO | set_property PACKAGE_PIN E18 [get_ports {SBUS_3V3_D[17]}] set_property IOSTANDARD LVTTL [get_ports {SBUS_3V3_D[17]}] | set_input_delay -clock SBUS_3V3_CLK -min 0,822 [get_ports {SBUS_3V3_D[17]}] set_input_delay -clock SBUS_3V3_CLK -max 25,346 [get_ports {SBUS_3V3_D[17]}] | set_output_delay -clock SBUS_3V3_CLK -min -1,985 [get_ports {SBUS_3V3_D[17]}] set_output_delay -clock SBUS_3V3_CLK -max 21,187 [get_ports {SBUS_3V3_D[17]}] |  | set_input_delay -clock SBUS_3V3_CLK -min 0,822 [get_ports {SBUS_3V3_D[17]}] set_input_delay -clock SBUS_3V3_CLK -max 25,346 [get_ports {SBUS_3V3_D[17]}] set_output_delay -clock SBUS_3V3_CLK -min -1,985 [get_ports {SBUS_3V3_D[17]}] set_output_delay -clock SBUS_3V3_CLK -max 21,187 [get_ports {SBUS_3V3_D[17]}]
B12 | F15~IO_L14P_T2_SRCC_15 | VCCO_AB | F15 |  | SRCC | 24 | SBUS_3V3_D[18] | F15~IO_L14P_T2_SRCC_15 | SBUS_3V3_D[18] | 26.76 | 35.42 |  | 62.18 | 2.45 |  | -17.81 | IO | set_property PACKAGE_PIN F15 [get_ports {SBUS_3V3_D[18]}] set_property IOSTANDARD LVTTL [get_ports {SBUS_3V3_D[18]}] | set_input_delay -clock SBUS_3V3_CLK -min 0,839 [get_ports {SBUS_3V3_D[18]}] set_input_delay -clock SBUS_3V3_CLK -max 25,369 [get_ports {SBUS_3V3_D[18]}] | set_output_delay -clock SBUS_3V3_CLK -min -1,967 [get_ports {SBUS_3V3_D[18]}] set_output_delay -clock SBUS_3V3_CLK -max 21,210 [get_ports {SBUS_3V3_D[18]}] |  | set_input_delay -clock SBUS_3V3_CLK -min 0,839 [get_ports {SBUS_3V3_D[18]}] set_input_delay -clock SBUS_3V3_CLK -max 25,369 [get_ports {SBUS_3V3_D[18]}] set_output_delay -clock SBUS_3V3_CLK -min -1,967 [get_ports {SBUS_3V3_D[18]}] set_output_delay -clock SBUS_3V3_CLK -max 21,210 [get_ports {SBUS_3V3_D[18]}]
A13 | D18~IO_L21N_T3_DQS_A18_15 | VCCO_AB | D18 |  |  | 25 | SBUS_3V3_D[20] | D18~IO_L21N_T3_DQS_A18_15 | SBUS_3V3_D[20] | 25.47 | 34.93 |  | 60.40 | 2.38 |  | -16.04 | IO | set_property PACKAGE_PIN D18 [get_ports {SBUS_3V3_D[20]}] set_property IOSTANDARD LVTTL [get_ports {SBUS_3V3_D[20]}] | set_input_delay -clock SBUS_3V3_CLK -min 0,830 [get_ports {SBUS_3V3_D[20]}] set_input_delay -clock SBUS_3V3_CLK -max 25,357 [get_ports {SBUS_3V3_D[20]}] | set_output_delay -clock SBUS_3V3_CLK -min -1,976 [get_ports {SBUS_3V3_D[20]}] set_output_delay -clock SBUS_3V3_CLK -max 21,198 [get_ports {SBUS_3V3_D[20]}] |  | set_input_delay -clock SBUS_3V3_CLK -min 0,830 [get_ports {SBUS_3V3_D[20]}] set_input_delay -clock SBUS_3V3_CLK -max 25,357 [get_ports {SBUS_3V3_D[20]}] set_output_delay -clock SBUS_3V3_CLK -min -1,976 [get_ports {SBUS_3V3_D[20]}] set_output_delay -clock SBUS_3V3_CLK -max 21,198 [get_ports {SBUS_3V3_D[20]}]
B13 | E17~IO_L16P_T2_A28_15 | VCCO_AB | E17 |  |  | 26 | SBUS_3V3_D[21] | E17~IO_L16P_T2_A28_15 | SBUS_3V3_D[21] | 23.54 | 35.57 |  | 59.11 | 2.33 |  | -14.74 | IO | set_property PACKAGE_PIN E17 [get_ports {SBUS_3V3_D[21]}] set_property IOSTANDARD LVTTL [get_ports {SBUS_3V3_D[21]}] | set_input_delay -clock SBUS_3V3_CLK -min 0,824 [get_ports {SBUS_3V3_D[21]}] set_input_delay -clock SBUS_3V3_CLK -max 25,348 [get_ports {SBUS_3V3_D[21]}] | set_output_delay -clock SBUS_3V3_CLK -min -1,983 [get_ports {SBUS_3V3_D[21]}] set_output_delay -clock SBUS_3V3_CLK -max 21,190 [get_ports {SBUS_3V3_D[21]}] |  | set_input_delay -clock SBUS_3V3_CLK -min 0,824 [get_ports {SBUS_3V3_D[21]}] set_input_delay -clock SBUS_3V3_CLK -max 25,348 [get_ports {SBUS_3V3_D[21]}] set_output_delay -clock SBUS_3V3_CLK -min -1,983 [get_ports {SBUS_3V3_D[21]}] set_output_delay -clock SBUS_3V3_CLK -max 21,190 [get_ports {SBUS_3V3_D[21]}]
A14 | G13~IO_0_15 | VCCO_AB | G13 |  |  | 27 | SBUS_3V3_D[23] | G13~IO_0_15 | SBUS_3V3_D[23] | 33.51 | 37.26 |  | 70.77 | 2.79 |  | -26.40 | IO | set_property PACKAGE_PIN G13 [get_ports {SBUS_3V3_D[23]}] set_property IOSTANDARD LVTTL [get_ports {SBUS_3V3_D[23]}] | set_input_delay -clock SBUS_3V3_CLK -min 0,882 [get_ports {SBUS_3V3_D[23]}] set_input_delay -clock SBUS_3V3_CLK -max 25,426 [get_ports {SBUS_3V3_D[23]}] | set_output_delay -clock SBUS_3V3_CLK -min -1,924 [get_ports {SBUS_3V3_D[23]}] set_output_delay -clock SBUS_3V3_CLK -max 21,268 [get_ports {SBUS_3V3_D[23]}] |  | set_input_delay -clock SBUS_3V3_CLK -min 0,882 [get_ports {SBUS_3V3_D[23]}] set_input_delay -clock SBUS_3V3_CLK -max 25,426 [get_ports {SBUS_3V3_D[23]}] set_output_delay -clock SBUS_3V3_CLK -min -1,924 [get_ports {SBUS_3V3_D[23]}] set_output_delay -clock SBUS_3V3_CLK -max 21,268 [get_ports {SBUS_3V3_D[23]}]
B14 | D17~IO_L16N_T2_A27_15 | VCCO_AB | D17 |  |  | 28 | SBUS_3V3_D[24] | D17~IO_L16N_T2_A27_15 | SBUS_3V3_D[24] | 21.66 | 35.27 |  | 56.93 | 2.24 |  | -12.56 | IO | set_property PACKAGE_PIN D17 [get_ports {SBUS_3V3_D[24]}] set_property IOSTANDARD LVTTL [get_ports {SBUS_3V3_D[24]}] | set_input_delay -clock SBUS_3V3_CLK -min 0,813 [get_ports {SBUS_3V3_D[24]}] set_input_delay -clock SBUS_3V3_CLK -max 25,334 [get_ports {SBUS_3V3_D[24]}] | set_output_delay -clock SBUS_3V3_CLK -min -1,994 [get_ports {SBUS_3V3_D[24]}] set_output_delay -clock SBUS_3V3_CLK -max 21,175 [get_ports {SBUS_3V3_D[24]}] |  | set_input_delay -clock SBUS_3V3_CLK -min 0,813 [get_ports {SBUS_3V3_D[24]}] set_input_delay -clock SBUS_3V3_CLK -max 25,334 [get_ports {SBUS_3V3_D[24]}] set_output_delay -clock SBUS_3V3_CLK -min -1,994 [get_ports {SBUS_3V3_D[24]}] set_output_delay -clock SBUS_3V3_CLK -max 21,175 [get_ports {SBUS_3V3_D[24]}]
A15 | 3.3V |  |  |  |  | 29 | #N/A |  |  |  | #N/A |  |  | 0.00
B15 | 3.3V |  |  |  |  | 30 | #N/A |  |  |  | #N/A |  |  | 0.00
A16 | GND |  |  |  |  | 31 | #N/A |  |  |  | #N/A |  |  | 0.00
B16 | GND |  |  |  |  | 32 | #N/A |  |  |  | #N/A |  |  | 0.00
A17 | VCCO_AB |  |  |  | default: 3.3V output, if R8 removed: 1.2V .. 3.3V input | 33 | #N/A |  |  |  | #N/A |  |  | 0.00
B17 | VCCO_AB |  |  |  | default: 3.3V output, if R8 removed: 1.2V .. 3.3V input | 34 | #N/A |  |  |  | #N/A |  |  | 0.00
A18 | F13~IO_L5P_T0_AD9P_15 | VCCO_AB | F13 |  |  | 35 | SBUS_3V3_D[30] | F13~IO_L5P_T0_AD9P_15 | SBUS_3V3_D[30] | 19.12 | 35.99 |  | 55.11 | 2.17 |  | -10.74 | IO | set_property PACKAGE_PIN F13 [get_ports {SBUS_3V3_D[30]}] set_property IOSTANDARD LVTTL [get_ports {SBUS_3V3_D[30]}] | set_input_delay -clock SBUS_3V3_CLK -min 0,804 [get_ports {SBUS_3V3_D[30]}] set_input_delay -clock SBUS_3V3_CLK -max 25,322 [get_ports {SBUS_3V3_D[30]}] | set_output_delay -clock SBUS_3V3_CLK -min -2,003 [get_ports {SBUS_3V3_D[30]}] set_output_delay -clock SBUS_3V3_CLK -max 21,163 [get_ports {SBUS_3V3_D[30]}] |  | set_input_delay -clock SBUS_3V3_CLK -min 0,804 [get_ports {SBUS_3V3_D[30]}] set_input_delay -clock SBUS_3V3_CLK -max 25,322 [get_ports {SBUS_3V3_D[30]}] set_output_delay -clock SBUS_3V3_CLK -min -2,003 [get_ports {SBUS_3V3_D[30]}] set_output_delay -clock SBUS_3V3_CLK -max 21,163 [get_ports {SBUS_3V3_D[30]}]
B18 | F14~IO_L5N_T0_AD9N_15 | VCCO_AB | F14 |  |  | 36 | SBUS_3V3_D[31] | F14~IO_L5N_T0_AD9N_15 | SBUS_3V3_D[31] | 12.94 | 38.90 |  | 51.84 | 2.04 |  | -7.47 | IO | set_property PACKAGE_PIN F14 [get_ports {SBUS_3V3_D[31]}] set_property IOSTANDARD LVTTL [get_ports {SBUS_3V3_D[31]}] | set_input_delay -clock SBUS_3V3_CLK -min 0,787 [get_ports {SBUS_3V3_D[31]}] set_input_delay -clock SBUS_3V3_CLK -max 25,300 [get_ports {SBUS_3V3_D[31]}] | set_output_delay -clock SBUS_3V3_CLK -min -2,019 [get_ports {SBUS_3V3_D[31]}] set_output_delay -clock SBUS_3V3_CLK -max 21,141 [get_ports {SBUS_3V3_D[31]}] |  | set_input_delay -clock SBUS_3V3_CLK -min 0,787 [get_ports {SBUS_3V3_D[31]}] set_input_delay -clock SBUS_3V3_CLK -max 25,300 [get_ports {SBUS_3V3_D[31]}] set_output_delay -clock SBUS_3V3_CLK -min -2,019 [get_ports {SBUS_3V3_D[31]}] set_output_delay -clock SBUS_3V3_CLK -max 21,141 [get_ports {SBUS_3V3_D[31]}]
A19 | E16~IO_L11N_T1_SRCC_15 | VCCO_AB | E16 |  | SRCC | 37 | SBUS_3V3_SIZ[0] | E16~IO_L11N_T1_SRCC_15 | SBUS_3V3_SIZ[0] | 16.11 | 72.71 |  | 88.82 | 3.50 |  | -44.45 | IO | set_property PACKAGE_PIN E16 [get_ports {SBUS_3V3_SIZ[0]}] set_property IOSTANDARD LVTTL [get_ports {SBUS_3V3_SIZ[0]}] | set_input_delay -clock SBUS_3V3_CLK -min 0,972 [get_ports {SBUS_3V3_SIZ[0]}] set_input_delay -clock SBUS_3V3_CLK -max 25,546 [get_ports {SBUS_3V3_SIZ[0]}] | set_output_delay -clock SBUS_3V3_CLK -min -1,834 [get_ports {SBUS_3V3_SIZ[0]}] set_output_delay -clock SBUS_3V3_CLK -max 21,388 [get_ports {SBUS_3V3_SIZ[0]}] |  | set_input_delay -clock SBUS_3V3_CLK -min 0,972 [get_ports {SBUS_3V3_SIZ[0]}] set_input_delay -clock SBUS_3V3_CLK -max 25,546 [get_ports {SBUS_3V3_SIZ[0]}] set_output_delay -clock SBUS_3V3_CLK -min -1,834 [get_ports {SBUS_3V3_SIZ[0]}] set_output_delay -clock SBUS_3V3_CLK -max 21,388 [get_ports {SBUS_3V3_SIZ[0]}]
B19 | E15~IO_L11P_T1_SRCC_15 | VCCO_AB | E15 |  | SRCC | 38 | SBUS_3V3_PPRD | E15~IO_L11P_T1_SRCC_15 | SBUS_3V3_PPRD | 10.5 | 67.98 |  | 78.48 | 3.09 |  | -34.12 | IO | set_property PACKAGE_PIN E15 [get_ports {SBUS_3V3_PPRD}] set_property IOSTANDARD LVTTL [get_ports {SBUS_3V3_PPRD}] | set_input_delay -clock SBUS_3V3_CLK -min 0,921 [get_ports {SBUS_3V3_PPRD}] set_input_delay -clock SBUS_3V3_CLK -max 25,477 [get_ports {SBUS_3V3_PPRD}] | set_output_delay -clock SBUS_3V3_CLK -min -1,886 [get_ports {SBUS_3V3_PPRD}] set_output_delay -clock SBUS_3V3_CLK -max 21,319 [get_ports {SBUS_3V3_PPRD}] |  | set_input_delay -clock SBUS_3V3_CLK -min 0,921 [get_ports {SBUS_3V3_PPRD}] set_input_delay -clock SBUS_3V3_CLK -max 25,477 [get_ports {SBUS_3V3_PPRD}] set_output_delay -clock SBUS_3V3_CLK -min -1,886 [get_ports {SBUS_3V3_PPRD}] set_output_delay -clock SBUS_3V3_CLK -max 21,319 [get_ports {SBUS_3V3_PPRD}]
A20 | C17~IO_L20N_T3_A19_15 | VCCO_AB | C17 |  |  | 39 | SBUS_3V3_PA[01] | C17~IO_L20N_T3_A19_15 | SBUS_3V3_PA[01] | 12.52 | 33.66 |  | 46.18 | 1.82 |  | -1.81 | IO | set_property PACKAGE_PIN C17 [get_ports {SBUS_3V3_PA[01]}] set_property IOSTANDARD LVTTL [get_ports {SBUS_3V3_PA[01]}] | set_input_delay -clock SBUS_3V3_CLK -min 0,759 [get_ports {SBUS_3V3_PA[01]}] set_input_delay -clock SBUS_3V3_CLK -max 25,262 [get_ports {SBUS_3V3_PA[01]}] | set_output_delay -clock SBUS_3V3_CLK -min -2,047 [get_ports {SBUS_3V3_PA[01]}] set_output_delay -clock SBUS_3V3_CLK -max 21,104 [get_ports {SBUS_3V3_PA[01]}] |  | set_input_delay -clock SBUS_3V3_CLK -min 0,759 [get_ports {SBUS_3V3_PA[01]}] set_input_delay -clock SBUS_3V3_CLK -max 25,262 [get_ports {SBUS_3V3_PA[01]}] set_output_delay -clock SBUS_3V3_CLK -min -2,047 [get_ports {SBUS_3V3_PA[01]}] set_output_delay -clock SBUS_3V3_CLK -max 21,104 [get_ports {SBUS_3V3_PA[01]}]
B20 | C16~IO_L20P_T3_A20_15 | VCCO_AB | C16 |  |  | 40 | SBUS_3V3_PA[00] | C16~IO_L20P_T3_A20_15 | SBUS_3V3_PA[00] | 7.79 | 40.70 |  | 48.49 | 1.91 |  | -4.13 | IO | set_property PACKAGE_PIN C16 [get_ports {SBUS_3V3_PA[00]}] set_property IOSTANDARD LVTTL [get_ports {SBUS_3V3_PA[00]}] | set_input_delay -clock SBUS_3V3_CLK -min 0,771 [get_ports {SBUS_3V3_PA[00]}] set_input_delay -clock SBUS_3V3_CLK -max 25,278 [get_ports {SBUS_3V3_PA[00]}] | set_output_delay -clock SBUS_3V3_CLK -min -2,036 [get_ports {SBUS_3V3_PA[00]}] set_output_delay -clock SBUS_3V3_CLK -max 21,119 [get_ports {SBUS_3V3_PA[00]}] |  | set_input_delay -clock SBUS_3V3_CLK -min 0,771 [get_ports {SBUS_3V3_PA[00]}] set_input_delay -clock SBUS_3V3_CLK -max 25,278 [get_ports {SBUS_3V3_PA[00]}] set_output_delay -clock SBUS_3V3_CLK -min -2,036 [get_ports {SBUS_3V3_PA[00]}] set_output_delay -clock SBUS_3V3_CLK -max 21,119 [get_ports {SBUS_3V3_PA[00]}]
A21 | A18~IO_L10N_T1_AD11N_15 | VCCO_AB | A18 |  |  | 41 | SBUS_3V3_PA[02] | A18~IO_L10N_T1_AD11N_15 | SBUS_3V3_PA[02] | 11.42 | 39.29 |  | 50.71 | 2.00 |  | -6.34 | IO | set_property PACKAGE_PIN A18 [get_ports {SBUS_3V3_PA[02]}] set_property IOSTANDARD LVTTL [get_ports {SBUS_3V3_PA[02]}] | set_input_delay -clock SBUS_3V3_CLK -min 0,782 [get_ports {SBUS_3V3_PA[02]}] set_input_delay -clock SBUS_3V3_CLK -max 25,292 [get_ports {SBUS_3V3_PA[02]}] | set_output_delay -clock SBUS_3V3_CLK -min -2,025 [get_ports {SBUS_3V3_PA[02]}] set_output_delay -clock SBUS_3V3_CLK -max 21,134 [get_ports {SBUS_3V3_PA[02]}] |  | set_input_delay -clock SBUS_3V3_CLK -min 0,782 [get_ports {SBUS_3V3_PA[02]}] set_input_delay -clock SBUS_3V3_CLK -max 25,292 [get_ports {SBUS_3V3_PA[02]}] set_output_delay -clock SBUS_3V3_CLK -min -2,025 [get_ports {SBUS_3V3_PA[02]}] set_output_delay -clock SBUS_3V3_CLK -max 21,134 [get_ports {SBUS_3V3_PA[02]}]
B21 | B18~IO_L10P_T1_AD11P_15 | VCCO_AB | B18 |  |  | 42 | SBUS_3V3_PA[05] | B18~IO_L10P_T1_AD11P_15 | SBUS_3V3_PA[05] | 4.99 | 35.87 |  | 40.86 | 1.61 |  | 3.50 | IO | set_property PACKAGE_PIN B18 [get_ports {SBUS_3V3_PA[05]}] set_property IOSTANDARD LVTTL [get_ports {SBUS_3V3_PA[05]}] | set_input_delay -clock SBUS_3V3_CLK -min 0,732 [get_ports {SBUS_3V3_PA[05]}] set_input_delay -clock SBUS_3V3_CLK -max 25,227 [get_ports {SBUS_3V3_PA[05]}] | set_output_delay -clock SBUS_3V3_CLK -min -2,074 [get_ports {SBUS_3V3_PA[05]}] set_output_delay -clock SBUS_3V3_CLK -max 21,068 [get_ports {SBUS_3V3_PA[05]}] |  | set_input_delay -clock SBUS_3V3_CLK -min 0,732 [get_ports {SBUS_3V3_PA[05]}] set_input_delay -clock SBUS_3V3_CLK -max 25,227 [get_ports {SBUS_3V3_PA[05]}] set_output_delay -clock SBUS_3V3_CLK -min -2,074 [get_ports {SBUS_3V3_PA[05]}] set_output_delay -clock SBUS_3V3_CLK -max 21,068 [get_ports {SBUS_3V3_PA[05]}]
A22 | C15~IO_L12N_T1_MRCC_15 | VCCO_AB | C15 |  | MRCC | 43 | SBUS_3V3_EER* | C15~IO_L12N_T1_MRCC_15 | SBUS_3V3_EER* | 16.17 | 36.14 |  | 52.31 | 2.06 |  | -7.94 | IO | set_property PACKAGE_PIN C15 [get_ports {SBUS_3V3_EER*}] set_property IOSTANDARD LVTTL [get_ports {SBUS_3V3_EER*}] | set_input_delay -clock SBUS_3V3_CLK -min 0,790 [get_ports {SBUS_3V3_EER*}] set_input_delay -clock SBUS_3V3_CLK -max 25,303 [get_ports {SBUS_3V3_EER*}] | set_output_delay -clock SBUS_3V3_CLK -min -2,017 [get_ports {SBUS_3V3_EER*}] set_output_delay -clock SBUS_3V3_CLK -max 21,145 [get_ports {SBUS_3V3_EER*}] |  | set_input_delay -clock SBUS_3V3_CLK -min 0,790 [get_ports {SBUS_3V3_EER*}] set_input_delay -clock SBUS_3V3_CLK -max 25,303 [get_ports {SBUS_3V3_EER*}] set_output_delay -clock SBUS_3V3_CLK -min -2,017 [get_ports {SBUS_3V3_EER*}] set_output_delay -clock SBUS_3V3_CLK -max 21,145 [get_ports {SBUS_3V3_EER*}]
B22 | D15~IO_L12P_T1_MRCC_15 | VCCO_AB | D15 |  | MRCC | 44 | SBUS_3V3_PA[07] | D15~IO_L12P_T1_MRCC_15 | SBUS_3V3_PA[07] | 7.67 | 36.70 |  | 44.37 | 1.75 |  | 0.00 |  | set_property PACKAGE_PIN D15 [get_ports {SBUS_3V3_PA[07]}] set_property IOSTANDARD LVTTL [get_ports {SBUS_3V3_PA[07]}] | set_input_delay -clock SBUS_3V3_CLK -min 0,750 [get_ports {SBUS_3V3_PA[07]}] set_input_delay -clock SBUS_3V3_CLK -max 25,250 [get_ports {SBUS_3V3_PA[07]}] | set_output_delay -clock SBUS_3V3_CLK -min -2,056 [get_ports {SBUS_3V3_PA[07]}] set_output_delay -clock SBUS_3V3_CLK -max 21,092 [get_ports {SBUS_3V3_PA[07]}]
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

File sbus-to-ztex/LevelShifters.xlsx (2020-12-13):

 |  |  |  |  | FPGA side (LVCMOS33) |  |  |  | SBUS side (TLL-compatible CMOS)
Family | Mfr. | Part | Datasheet | #signals | V_IL low | V_IL high | V_OL low | V_OL high | V_IL low | V_IL high | V_OL low | V_OL high | VCC low | VCC high | Prop Delay A->B | Enable Delay
 |  |  |  |  | 0.8 | 2 | 0.4 | 2.4 | 0.8 | 2 | 0.4 | 2.4
74LVC | TI | SN74LVC8T245 | https://www.ti.com/lit/ds/sces584b/sces584b.pdf | 8 | 0.8 | 2 |  |  | 2 | 3.5 |  |  | 3.3 | 5
74HVC | ON Semi | 74VHCT245A | https://www.onsemi.com/pub/Collateral/74VHCT245A-D.pdf | 8 | 0.8 | 2 |  | 4.5 | 0.8 | 2 | 0.4 | 4.5 | N/A | 5 | 8.5 | 16.5
74ALVT | Nexperia / NXP | 74ALVT162245 | https://assets.nexperia.com/documents/data-sheet/74ALVT162245.pdf | 16 | 0.8 | 2 | 0.8 | 2 | 0.8 | 2 | 0.8 | 2 | 3.3 | N/A
74LVC | TI | SN74LVC16245A | https://www.ti.com/lit/ds/symlink/sn74lvc16245a.pdf | 16 | 0.8 | 2 | 0.4 | 2.4 | 0.8 | 2 | 0.4 | 2.4 | 3.3 | N/A | 4 | 6.6
74LVC | IDT / Renesas | IDT74LVC16245A | https://www.idt.com/eu/en/document/dst/74lvc16245a-datasheet | 16 | 0.8 | 2 | 0.4 | 2.4 | 0.8 | 2 | 0.4 | 2.4 | 3.3 | N/A | 4 | 6.6
74LVC | Nexperia / NXP | 74LVC245A | https://assets.nexperia.com/documents/data-sheet/74LVC_LVCH245A.pdf | 8 | 0.8 | 2 | 0.4 | 2.4 | 0.8 | 2 | 0.4 | 2.4 | 3.3 | N/A | 6.3 | 8.5
74LVC | Nexperia / NXP | 74LVC16245A | https://assets.nexperia.com/documents/data-sheet/74LVC_LVCH16245A.pdf | 16 | 0.8 | 2 | 0.4 | 2.4 | 0.8 | 2 | 0.4 | 2.4 | 3.3 | N/A | 4.5 | 5.5
74LVT | TI | SN74LVT162245A | https://www.ti.com/lit/ds/symlink/sn74lvt162245a.pdf | 16 | 0.8 | 2 | 0.4 | 2.4 | 0.8 | 2 | 0.4 | 2.4 | 3.3 | N/A | 3.3 | 4.6 | TheinputcircuitryonbothAandBportsisalwaysactiveandmusthavealogicHIGHorLOWlevelappliedtopreventexcessICCandICCZ
74LVT | TI | SN74LVT16245B | https://www.ti.com/lit/ds/symlink/sn74lvt16245b.pdf | 16 | 0.8 | 2 | 0.4 | 2.4 | 0.8 | 2 | 0.4 | 2.4 | 3.3 | N/A | 4.5 | 5.1
 |  | 74LVX16245 | not readily available
74LVX | ON Semi | 74LVX245 | https://www.mouser.com/datasheet/2/149/74LVX245-1006665.pdf | 8 | 0.8 | 2.2 | 0.1 | 2.9 | 0.8 | 2.2 | 0.1 | 2.9 | 3.3 |  | 10.1 | 14.5
74LCX | ON Semi | 74LCX245 | https://www.mouser.com/datasheet/2/149/74LCX245-21038.pdf | 8 | 0.8 | 2 | 0.4 | 2.4 | 0.8 | 2 | 0.4 | 2.4 | 3.3 |  | 7 | 8.5
74LCX | Toshiba | 74LCX245 | https://www.mouser.fr/datasheet/2/408/TC74LCX245F_datasheet_en_20140301-1369428.pdf | 8 | 0.8 | 2 | 0.4 | 2.4 | 0.8 | 2 | 0.4 | 2.4 | 3.3 |  | 7 | 8.5
 |  | UNIDIR
74LVC | Nexperia / NXP | 74LVC16244A | https://www.mouser.fr/datasheet/2/916/74LVC_LVCH16244A-1319452.pdf | 16 | 0.8 | 2 | 0.4 | 2.4 | 0.8 | 2 | 0.4 | 2.4 | 3.3 | N/A | 4.1 | 4.6
74LVC | Nexperia / NXP | 74LVC125A | https://www.ti.com/lit/ds/symlink/sn74lvc125a.pdf | 4 | 0.8 | 2 | 0.4 | 2.4 | 0.8 | 2 | 0.4 | 2.4 | 3.3 | N/A | 4.8 | 5.4
74LVC | Nexperia / NXP | 74LVC126A | https://www.mouser.fr/datasheet/2/916/74LVC126A-1319461.pdf | 4 | 0.8 | 2 | 0.4 | 2.4 | 0.8 | 2 | 0.4 | 2.4 | 3.3 | N/A | 4.7 | 5.7 | w/ shmitt trigger
74LVC | TI | SN74LVC244A | https://www.ti.com/lit/ds/symlink/sn74lvc244a.pdf | 8 | 0.8 | 2 | 0.4 | 2.4 | 0.8 | 2 | 0.4 | 2.4 | 3.3 |  | 5.9 | 7.6
74LVC | TI | SN74LVC541A | https://www.ti.com/lit/ds/symlink/sn74lvc541a.pdf | 8 | 0.8 | 2 | 0.8 | 2 | 0.8 | 2 | 0.8 | 2
74LVT | TI | SN74LVT240A | https://www.ti.com/lit/ds/symlink/sn74lvt240a.pdf | 8 | 0.8 | 2 | 0.4 | 2.4 | 0.8 | 2 | 0.4 | 2.4 | 3.3 | N/A | 4 | 4.4
 |  | OpenDrain O
 |  | SN74LVC1G07 |  | 1
 |  | SN74LVC2G07 |  | 2

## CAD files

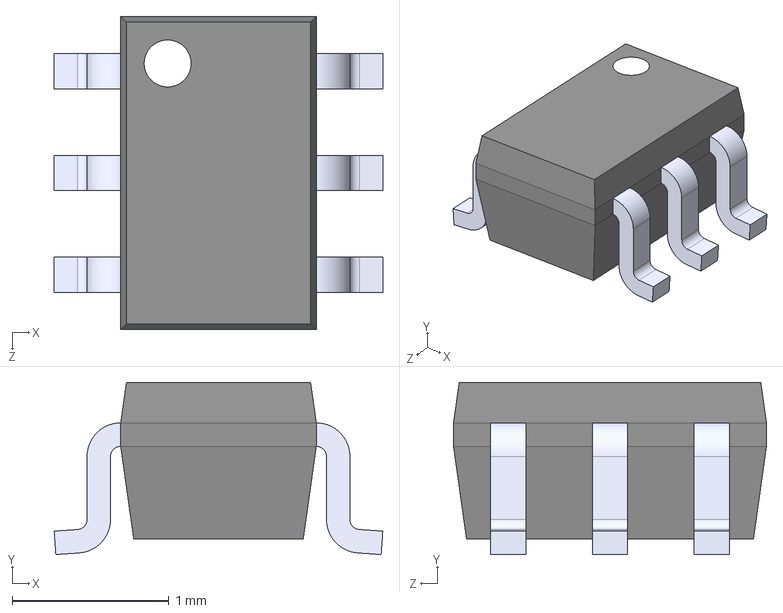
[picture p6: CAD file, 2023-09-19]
sbus-to-ztex/SN74LVC2G07DCKR.step
2.10 x 1.10 x 2.00 mm

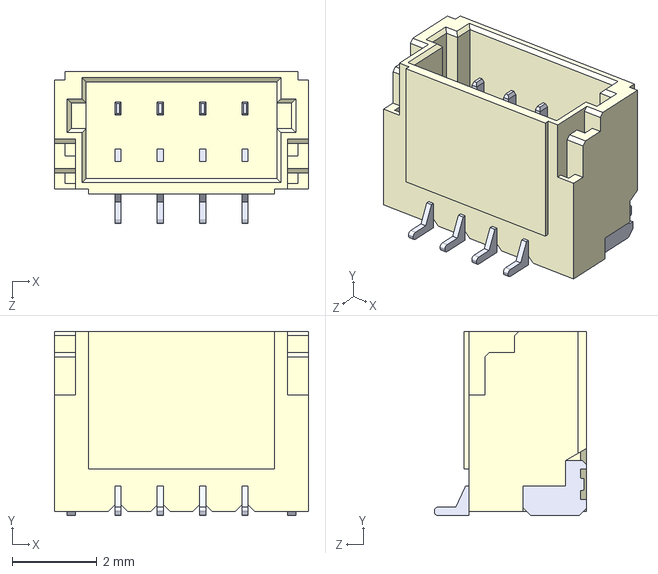
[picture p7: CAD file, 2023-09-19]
sbus-to-ztex/BM04B-SRSS-TB-LF--SN---3DModel-STEP-56544.STEP
6.00 x 4.35 x 3.60 mm

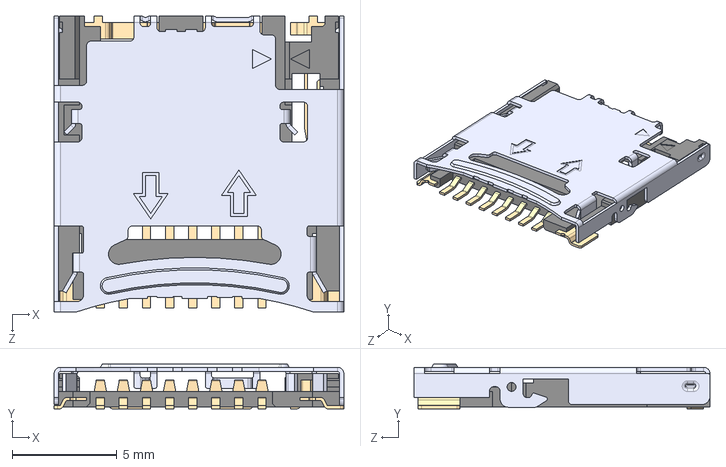
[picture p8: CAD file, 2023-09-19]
sbus-to-ztex/DM3CS-SF.step
13.8 x 2.13 x 14.1 mm

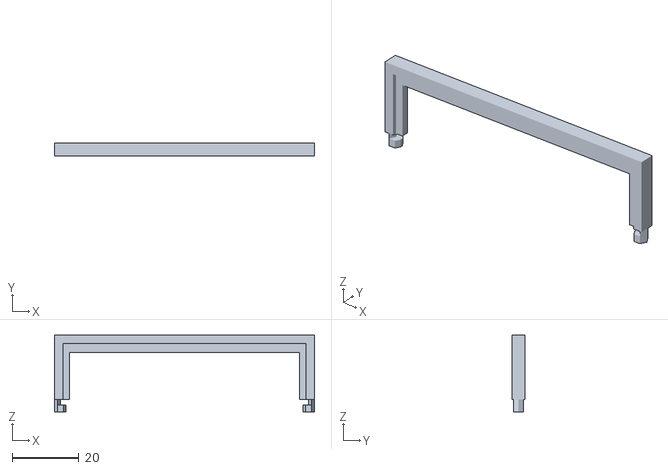
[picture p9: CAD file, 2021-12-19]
sbus-to-ztex/SBus_Retainer.stl
77.8 x 4.00 x 23.0

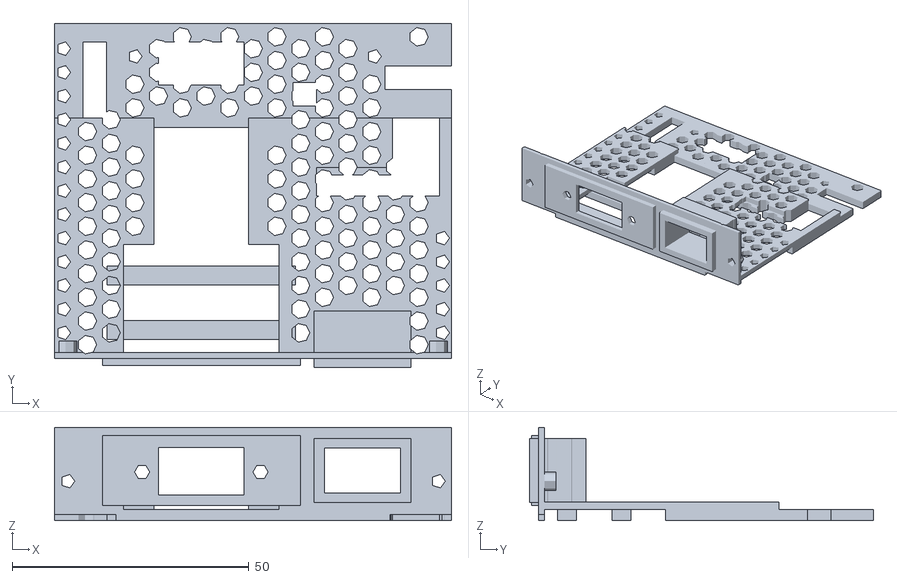
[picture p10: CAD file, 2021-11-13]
sbus-to-ztex/Backplate.stl
83.8 x 72.7 x 19.6

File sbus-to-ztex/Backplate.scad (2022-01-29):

add_fan = 1; // not really compatible with USB...
add_vga = 0;
add_usb = 1;
usb_angled = 1;

SBUS_WIDTH = 83.82;
SBUS_LENGTH = 146.7;
SBUS_THICKNESS = 1.6;
MYSBUS_MISSING_LENGTH = 47;

SBUS_BACKPLATE_THICKNESS = 1.19;
SBUS_BACKPLATE_FULLHEIGHT = 19.64;
SBUS_BACKPLATE_PROTUSION_HEIGHT = 1.22;
SBUS_BACKPLATE_HEIGHT = SBUS_BACKPLATE_FULLHEIGHT - SBUS_BACKPLATE_PROTUSION_HEIGHT;
SBUS_BACKPLATE_PROTUSION_FROMSIDE = 13;

SBUS_BACKPLATE_BOTTOM_TO_BOARD_BOTTOM = 1.12;

SBUS_GAP_BACKPLATE = 2.54;
SBUS_BACKPLATE_TOPHOLETOTOPHOLE = 79.24;
SBUS_BACKPLATE_TOPHOLEFROMSIDE = 2.29;
SBUS_BACKPLATE_TOPHOLEFROMBOTTOM = 15.43;
SBUS_BACKPLATE_TOPHOLEFROMFULLBOTTOM = SBUS_BACKPLATE_TOPHOLEFROMBOTTOM + SBUS_BACKPLATE_PROTUSION_HEIGHT;

SBUS_BACKPLATE_HOLESTOHOLES = 78.23;
SBUS_BACKPLATE_HOLEFROMSIDE = 2.795;
SBUS_BACKPLATE_HOLEFROMFULLBOTTOM = 7.08;
SBUS_BACKPLATE_HOLEFROMBOTTOM = SBUS_BACKPLATE_HOLEFROMFULLBOTTOM - SBUS_BACKPLATE_PROTUSION_HEIGHT;


SBUS_BACKPLATE_WIDTH = SBUS_BACKPLATE_TOPHOLETOTOPHOLE + 2 * SBUS_BACKPLATE_TOPHOLEFROMSIDE;
SBUS_BACKPLATE_PROTUSION_WIDTH = SBUS_BACKPLATE_WIDTH - 2 * SBUS_BACKPLATE_PROTUSION_FROMSIDE;

MY_FULL_LENGTH = MYSBUS_MISSING_LENGTH + SBUS_GAP_BACKPLATE + SBUS_BACKPLATE_THICKNESS;

//holes:
// 110,130.82
// 110,120.82
// 110,82
// top left 97,50
// -> 13,80.82 ; 13,70.82 ; 13,32 from top left

STRUT_HEIGHT = 10.01;		// max 15.31
STRUT_WIDTH = 3;
SMALL_STRUT_HEIGHT = 5;
SMALL_STRUT_WIDTH = 2;
SMALL_STRUT_LENGTH = 20;

USB_PLUG_OFFSET = (add_vga!=0 ? 65 : 30);
USB_PLUG_IDX = (add_vga!=0 ? 3 : -4);

fan_depth=8;
fan_height=25;
fan_width=fan_height;
fan_carrier_depth=5;
fan_extra_height=3;
vertical_offset=fan_height/2-SBUS_THICKNESS/2-(SBUS_BACKPLATE_PROTUSION_HEIGHT + SBUS_BACKPLATE_BOTTOM_TO_BOARD_BOTTOM)+fan_extra_height/2;
carrier_offset_from_backplate=5;
carrier_offset=-MY_FULL_LENGTH/2+fan_width/2+carrier_offset_from_backplate; // negative -> toward back

module
primary ()
{

    USBCABLE_HOLLOWOUT_WIDTH = 10;
    USBCABLE_HOLLOWOUT_LENGTH = 16.5;
    USBCABLE_HOLLOWOUT_OFFSETX = -7.5+0.001;
    USBCABLE_HOLLOWOUT_OFFSETY = -16.5;
    USBCABLE_HOLLOWOUT2_WIDTH = 21;
    USBCABLE_HOLLOWOUT2_LENGTH = 6;
    USBCABLE_HOLLOWOUT2_OFFSETX = -12.5;
    USBCABLE_HOLLOWOUT2_OFFSETY = -16.5;
    
    
  union () // A
  {
difference() { // B
    union() { // C
    color ("green") cube ([SBUS_WIDTH, MY_FULL_LENGTH, SBUS_THICKNESS], center = true);
    
    translate ([0, -MY_FULL_LENGTH / 2 + SBUS_BACKPLATE_THICKNESS / 2, SBUS_BACKPLATE_HEIGHT / 2 - SBUS_THICKNESS / 2 - SBUS_BACKPLATE_BOTTOM_TO_BOARD_BOTTOM]) {
      union ()
      {
	color ("black")
	  cube ([SBUS_BACKPLATE_WIDTH, SBUS_BACKPLATE_THICKNESS, SBUS_BACKPLATE_HEIGHT], center = true);
	translate ([0, 0, -SBUS_BACKPLATE_PROTUSION_HEIGHT / 2]) {
	  color ("black")
	    cube ([SBUS_BACKPLATE_PROTUSION_WIDTH, SBUS_BACKPLATE_THICKNESS, SBUS_BACKPLATE_FULLHEIGHT], center = true);
	}
      } // union
    }
    
    /* to fix the board to the machine */
    FIX_HOLES_STUB_LENGTH=3;
    translate ([-SBUS_WIDTH/2+(SBUS_WIDTH-SBUS_BACKPLATE_HOLESTOHOLES)/2,
        -MY_FULL_LENGTH / 2 + SBUS_BACKPLATE_THICKNESS / 2+FIX_HOLES_STUB_LENGTH/2,
        -SBUS_THICKNESS/2-SBUS_BACKPLATE_BOTTOM_TO_BOARD_BOTTOM+7.08]) rotate([90,0,0]) color ("black") cylinder (h = FIX_HOLES_STUB_LENGTH, r1 = 2, r2 = 2, center = true);
    translate ([+SBUS_WIDTH/2-(SBUS_WIDTH-SBUS_BACKPLATE_HOLESTOHOLES)/2,
        -MY_FULL_LENGTH / 2 + SBUS_BACKPLATE_THICKNESS / 2+FIX_HOLES_STUB_LENGTH/2,
        -SBUS_THICKNESS/2-SBUS_BACKPLATE_BOTTOM_TO_BOARD_BOTTOM+7.08]) rotate([90,0,0]) color ("black") cylinder (h = FIX_HOLES_STUB_LENGTH, r1 = 2, r2 = 2, center = true);
    
    /* USB plug (StarTech cable) */
    if (add_usb) {
    union() {
        color ("grey") 
      translate ([-SBUS_WIDTH/2+USB_PLUG_OFFSET,
        0.001-MY_FULL_LENGTH/2+4,
        14.8/2-SBUS_THICKNESS/2-SBUS_BACKPLATE_BOTTOM_TO_BOARD_BOTTOM-SBUS_BACKPLATE_PROTUSION_HEIGHT + 3.12])
	  cube ([16.5+4, 12, 9.5+4 /* 14.8 max */], center = true);
    }
    }

    if (0) for (i =[-2: 1:2]) {
	translate ([i * 15 + 2.5, 0, STRUT_HEIGHT / 2 - 0.1]) color ("red") cube ([STRUT_WIDTH, MY_FULL_LENGTH, STRUT_HEIGHT], center = true);
      }
  } // union C
  union() { // Z
      
    if (add_usb && usb_angled) {
	translate ([SBUS_WIDTH / 2 - USBCABLE_HOLLOWOUT_WIDTH / 2 + 5+ USBCABLE_HOLLOWOUT_OFFSETX,
                MY_FULL_LENGTH / 2 + USBCABLE_HOLLOWOUT_LENGTH / 2 + USBCABLE_HOLLOWOUT_OFFSETY,
                0]) {
	  color ("yellow")
	    cube ([USBCABLE_HOLLOWOUT_WIDTH, USBCABLE_HOLLOWOUT_LENGTH, 50], center = true);
	}
	translate ([SBUS_WIDTH / 2 - USBCABLE_HOLLOWOUT2_WIDTH / 2 + 5+ USBCABLE_HOLLOWOUT2_OFFSETX,
                MY_FULL_LENGTH / 2 + USBCABLE_HOLLOWOUT2_LENGTH / 2 + USBCABLE_HOLLOWOUT2_OFFSETY,
                0]) {
	  color ("yellow")
	    cube ([USBCABLE_HOLLOWOUT2_WIDTH, USBCABLE_HOLLOWOUT2_LENGTH, 50], center = true);
	}
    }
    
    /* to fix the board to the machine */
    translate ([-SBUS_WIDTH/2+(SBUS_WIDTH-SBUS_BACKPLATE_HOLESTOHOLES)/2,
        -MY_FULL_LENGTH / 2 + SBUS_BACKPLATE_THICKNESS / 2,
        -SBUS_THICKNESS/2-SBUS_BACKPLATE_BOTTOM_TO_BOARD_BOTTOM+7.08]) rotate([90,0,0]) color ("yellow") cylinder (h = 10, r1 = 1.5, r2 = 1.5, center = true);
    translate ([+SBUS_WIDTH/2-(SBUS_WIDTH-SBUS_BACKPLATE_HOLESTOHOLES)/2,
        -MY_FULL_LENGTH / 2 + SBUS_BACKPLATE_THICKNESS / 2,
        -SBUS_THICKNESS/2-SBUS_BACKPLATE_BOTTOM_TO_BOARD_BOTTOM+7.08]) rotate([90,0,0]) color ("yellow") cylinder (h = 10, r1 = 1.5, r2 = 1.5, center = true);
    
    /* USB plug (StarTech cable) */
    if (add_usb) {
    union() {
        color ("yellow") 
      translate ([-SBUS_WIDTH/2+USB_PLUG_OFFSET,
        0.001-MY_FULL_LENGTH/2+4,
        14.8/2-SBUS_THICKNESS/2-SBUS_BACKPLATE_BOTTOM_TO_BOARD_BOTTOM-SBUS_BACKPLATE_PROTUSION_HEIGHT + 3.12])
	  cube ([16, 20, 9.5], center = true);
    }
}
      
  } // union Z
  
  }// difference B
 
  //translate ([SBUS_WIDTH/2-18,7+(MY_FULL_LENGTH-SMALL_STRUT_LENGTH)/2,SMALL_STRUT_HEIGHT/2]) color("red") cube([SMALL_STRUT_WIDTH, SMALL_STRUT_LENGTH, SMALL_STRUT_HEIGHT], center = true);
  //translate ([-SBUS_WIDTH/2+24,7+(MY_FULL_LENGTH-SMALL_STRUT_LENGTH)/2,SMALL_STRUT_HEIGHT/2]) color("red") cube([SMALL_STRUT_WIDTH, SMALL_STRUT_LENGTH, SMALL_STRUT_HEIGHT], center = true);

    MY_BOARD_OVERLAP_LENGTH = 20;
    MY_BACKPLATE_OVERLAP_LENGTH = 12;
    MY_OVERLAP_LENGTH = MY_BOARD_OVERLAP_LENGTH + MY_BACKPLATE_OVERLAP_LENGTH;

    FIXHOLE_X_OFFSET = 13;
    FIXHOLE1_Y_OFFSET = SBUS_WIDTH - 16.3;
    FIXHOLE2_Y_OFFSET = SBUS_WIDTH - 66.82;
    FIXHOLE3_Y_OFFSET = 32;

    FIXHOLE_RAD = 1.5;

    SERIAL_HOLLOWOUT_WIDTH = 18;
    SERIAL_HOLLOWOUT_LENGTH = 5;
    SERIAL_HOLLOWOUT_OFFSET = 3;

    PMOD_HOLLOWOUT_WIDTH = 18;
    PMOD_HOLLOWOUT_LENGTH = 9;
    PMOD_HOLLOWOUT_OFFSETX = (31 - SBUS_WIDTH) + PMOD_HOLLOWOUT_WIDTH / 2;
    PMOD_HOLLOWOUT_OFFSETY = 7;

    USB_HOLLOWOUT_WIDTH = 14;
    USB_HOLLOWOUT_LENGTH = 5;
    USB_HOLLOWOUT_OFFSETX = -5+0.001;
    USB_HOLLOWOUT_OFFSETY = 6;

    SDCARD_HOLLOWOUT_WIDTH = 5;
    SDCARD_HOLLOWOUT_LENGTH = 5;
    SDCARD_HOLLOWOUT_OFFSETX = -36+SDCARD_HOLLOWOUT_WIDTH/2+0.001;
    SDCARD_HOLLOWOUT_OFFSETY = 2.501;


    JTAG_HOLLOWOUT_WIDTH = 5;
    JTAG_HOLLOWOUT_LENGTH = 16;
    JTAG_HOLLOWOUT_OFFSET = 6;

    difference () { // I
        union () {
      translate ([0,
		  MY_FULL_LENGTH / 2 + MY_OVERLAP_LENGTH / 2 -
		  MY_BACKPLATE_OVERLAP_LENGTH, 0.00000000001 - SBUS_THICKNESS / 2 - (SBUS_BACKPLATE_PROTUSION_HEIGHT + SBUS_BACKPLATE_BOTTOM_TO_BOARD_BOTTOM) / 2]) {
	color ("blue")
	  cube ([SBUS_WIDTH, MY_OVERLAP_LENGTH,	/*SBUS_THICKNESS */
		 SBUS_BACKPLATE_PROTUSION_HEIGHT + SBUS_BACKPLATE_BOTTOM_TO_BOARD_BOTTOM], center = true);
      }
      
      STRUT_WIDTH=2;
      translate ([
		  SBUS_WIDTH/2-STRUT_WIDTH/2,
          -12+MY_FULL_LENGTH / 2 + MY_OVERLAP_LENGTH / 2 -
		  MY_BACKPLATE_OVERLAP_LENGTH, 0.00000000001 - SBUS_THICKNESS / 2 - (SBUS_BACKPLATE_PROTUSION_HEIGHT + SBUS_BACKPLATE_BOTTOM_TO_BOARD_BOTTOM) / 2]) {
	color ("blue")
	  cube ([STRUT_WIDTH, MY_OVERLAP_LENGTH,	/*SBUS_THICKNESS */
		 SBUS_BACKPLATE_PROTUSION_HEIGHT + SBUS_BACKPLATE_BOTTOM_TO_BOARD_BOTTOM], center = true);
      }
  }
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

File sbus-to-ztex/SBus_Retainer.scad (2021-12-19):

LENGTH = 77.8;
WIDTH = 4;
WIDTH2 = 2;
HEIGHT = 19.3;
THICKNESS = 2.5;
THICKNESS2V = 4;
THICKNESS2H = 2;
PINHEIGHT_HOLE = 1.7;
PINHEIGHT_THICK = 2;
PINHEIGHT = PINHEIGHT_HOLE + PINHEIGHT_THICK;
PIN_RADIUS = 3.6 / 2;
PIN_INT_WIDTH = 1.6;		// .2 short for flat surface
PINHOLE_OFFSET = 1.6;


module
body ()
{
  translate ([0, 0, -THICKNESS / 2]) cube ([LENGTH, WIDTH, THICKNESS],
					   center = true);
  translate ([0, 0, -THICKNESS / 2 - THICKNESS2V / 2]) cube ([LENGTH, WIDTH2,
							      THICKNESS2V],
							     center = true);
  color("pink") translate ([+LENGTH / 2 - THICKNESS/2, 0, -HEIGHT / 2]) cube ([THICKNESS, WIDTH, HEIGHT],
						  center = true);
  color("pink") translate ([-LENGTH / 2 + THICKNESS/2, 0, -HEIGHT / 2]) cube ([THICKNESS, WIDTH, HEIGHT],
						  center = true);
  color("blue") translate ([+LENGTH / 2-THICKNESS-THICKNESS2H/2, 0, -HEIGHT / 2]) cube ([THICKNESS2H,
							       WIDTH2,
							       HEIGHT],
							      center = true);
  color("blue") translate ([-LENGTH / 2+THICKNESS+THICKNESS2H/2, 0, -HEIGHT / 2]) cube ([THICKNESS2H,
							       WIDTH2,
							       HEIGHT],
							      center = true);
}

module
pin_negative_hole() {
    translate([0,0,PINHEIGHT/2-PINHEIGHT_HOLE/2])
    difference() {
    color ("purple") cylinder (r1 = 10, r2 = 10, h = PINHEIGHT_HOLE, center = true);
    color("black") translate([-1.8,0,0]) cylinder (r1 = PIN_RADIUS, r2 = PIN_RADIUS, h = 2*PINHEIGHT_HOLE, center = true);
    }
}

module
pin_negative ()
{
  union ()
  {
    difference ()
    {
      union ()
      {
	color ("purple") cylinder (r1 = 10, r2 = 10, h = 10, center = true);
      }
      union ()
      {
	cylinder (r1 = PIN_RADIUS, r2 = PIN_RADIUS, h = 30, center = true);
      }
    }

    color ("red") translate ([PIN_INT_WIDTH + 5, 0, 0]) cube ([10, 10, 10],
							      center = true);
    pin_negative_hole();
  }
}

module
pin ()
{
  translate([0,0,-PINHEIGHT/2])
    difference ()
  {
    union ()
    {
      translate([0,0,0.0001]) color ("green") cylinder (r1 = PIN_RADIUS, r2 = PIN_RADIUS, h =
				PINHEIGHT+0.0001, center = true);
    }
    pin_negative ();
  }
}

module retainer() {
    body();
    translate([-LENGTH/2+PIN_RADIUS,0,-HEIGHT]) pin();
    translate([+LENGTH/2-PIN_RADIUS,0,-HEIGHT]) rotate([0,0,180]) pin();
}

retainer();

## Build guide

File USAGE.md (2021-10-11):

# How to use A FPGA on a SBus card...

## What do you need ?

* a SPARCstation or compatible with a free SBus slot, high enough to accomodate the taller-than-the standard board. Only SPARCstation 20s have been tested so far. I'd recommend against a SPARCstation 1-class machine (1, 1+, SLC, ...) as they have many quirks in their early SBus implementation. OpenBoot 2.x or newer is also a requirement (i.e. a recent 2.x or newer PROM).

* [NetBSD](https://www.netbsd.org/) 9.0 running on the SPARCstation, presumably newer version would work as well but have not yet been tested. No other OS (SunOS 4.1, Solaris 2.x, ...) have drivers (it is theoretically possible to write some, but it isn't planned).

* The ability to [rebuild the NetBSD kernel from source](https://www.netbsd.org/docs/guide/en/chap-kernel.html), as extra drivers are needed. It is well documented by the NetBSD team. This can be done in a QEmu virtual machine running NetBSD/sparc as an alternative to doing it on the real hardware.

* An adequate FPGA board, namely a [ZTex USB-to-FPGA 2.13](https://www.ztex.de/usb-fpga-2/usb-fpga-2.13.e.html). It provides the actual FPGA, a Xilinx Artix-7, and 256 MiB of on-board DDR3 SDRAM. Any of the 2.13 should work, but only the 2.13a (smallest and slowest FPGA, cheapest board) has been tested and it enough to fit quite a lot of stuff already. Other non-2.13 boards from ZTex will not work due to pin assignement (e.g. restriction on which pin can take the SBus clock as input), voltage (some boards require strictly more than 5V as input), ...

* An adequate power supply to power the FPGA board out of the SPARCstation so it can be programmed, and either an install of the FOSS  ZTex software to program the board via USB (recommended!) or an adequate JTAG programmer to program the board from Vivado

* The [Xilinx Vivado toolchain](https://www.xilinx.com/support/download/index.html/content/xilinx/en/downloadNav/vivado-design-tools/2020-2.html) to work with the FPGA. I use 2020.1, newer should work as well (and maybe some older). The free (as in no money needed, not as in FOSS)version is enough for the Artix-7 FPGA.

* A SBusFPGA SBus board. There's no supplier for those. Mine were manufactured by SeeedStudio. Other suppliers of PCB and PCB assembly are available - it's just the one I'm used to.

* A working [Litex](https://github.com/enjoy-digital/litex/) installation. It supplies the basis and many functionalities of the gateware in the FPGA.

* The ability to 3D-print the extension (and associated backplate), so that the board can be installed cleanly in a SBus system

* ???

## How to rebuild

* TBD

## Known limitations

* Currently, the board delays its powering-up by 20s after a cold start. That means that the host SPARCstation will POST without the board and not see it. The machine must be reset at the prompt, or the slot must be explictely probed, for the board to become visible. This is because so far, having the board start-up right away will prevent the SPARCstation from POSTing for unknown reasons.

* The combined height of the SBusFPGA and the FPGA daughterboard exceed the SBus limitation, and so may not fit in some systems.

* ???

TBD

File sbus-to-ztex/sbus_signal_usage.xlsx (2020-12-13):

 |  | Controller | Master | Slave
CLK | 1 | O | I | I
RST* | 1 | O | I | I
PA[] | 28 | O | [I/O] | I[/O] | Output for extended transfer only; Master: input for extended transfer only; can ignore some w/o ET
SEL* | 1 | O | - | I
AS* | 1 | O | - | I
BR* | 1 | I | O | -
BG* | 1 | O | I | -
D[],DP | 33 | I | I/O | I/O | Can (should?) ignore DP
SIZ[] | 3 | - | [I/]O | I[/O] | Slave: output for extended transfer only; Master: input for extended transfer only
RD | 1 | I | [I/]O | I[/O] | Slave: output for extended transfer only; Master: input for extended transfer only
ACK[]* | 3 | I/O | I | O
LERR* | 1 | I? | I | O
INT[]* | 7 | I |  | O | Open Drain
 | 82
I (w/o ET) |  |  | 40 | 69
I (w/ ET) |  |  | 72 | 69
O (w/o ET) |  |  | 45 | 44
O (w/ ET) |  |  | 73 | 76
I/O (w/o ET) |  |  | 33 | 33 | include DP
I/O (w ET) |  |  | 65 | 65 | include DP
Pure I (w/o ET) |  |  | 7 | 36 | include PA, can ignore some w/o ET; CLK/RST*/SEL*/AS* must be always-on
Pure I (w/ ET) |  |  | 7 | 4
Pure O (w/o ET) |  |  | 12 | 11 | include INT
Pure O (w/ ET) |  |  | 8 | 11

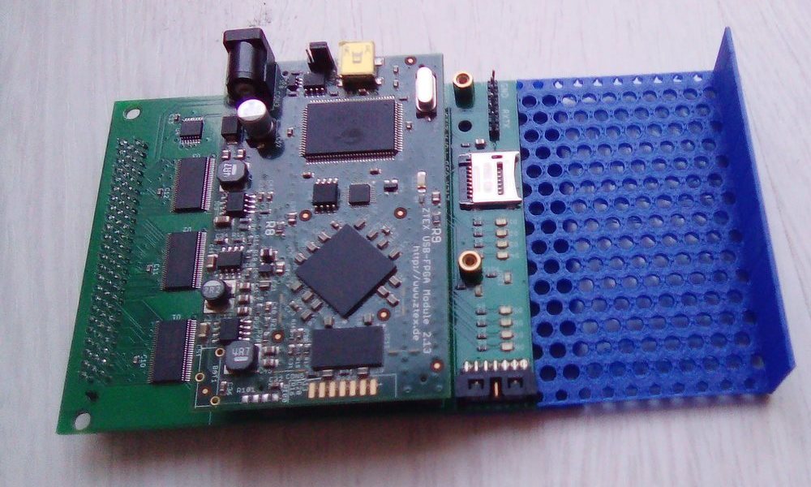
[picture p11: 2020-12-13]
Pictures/sbus-to-ztex-assembled.jpg

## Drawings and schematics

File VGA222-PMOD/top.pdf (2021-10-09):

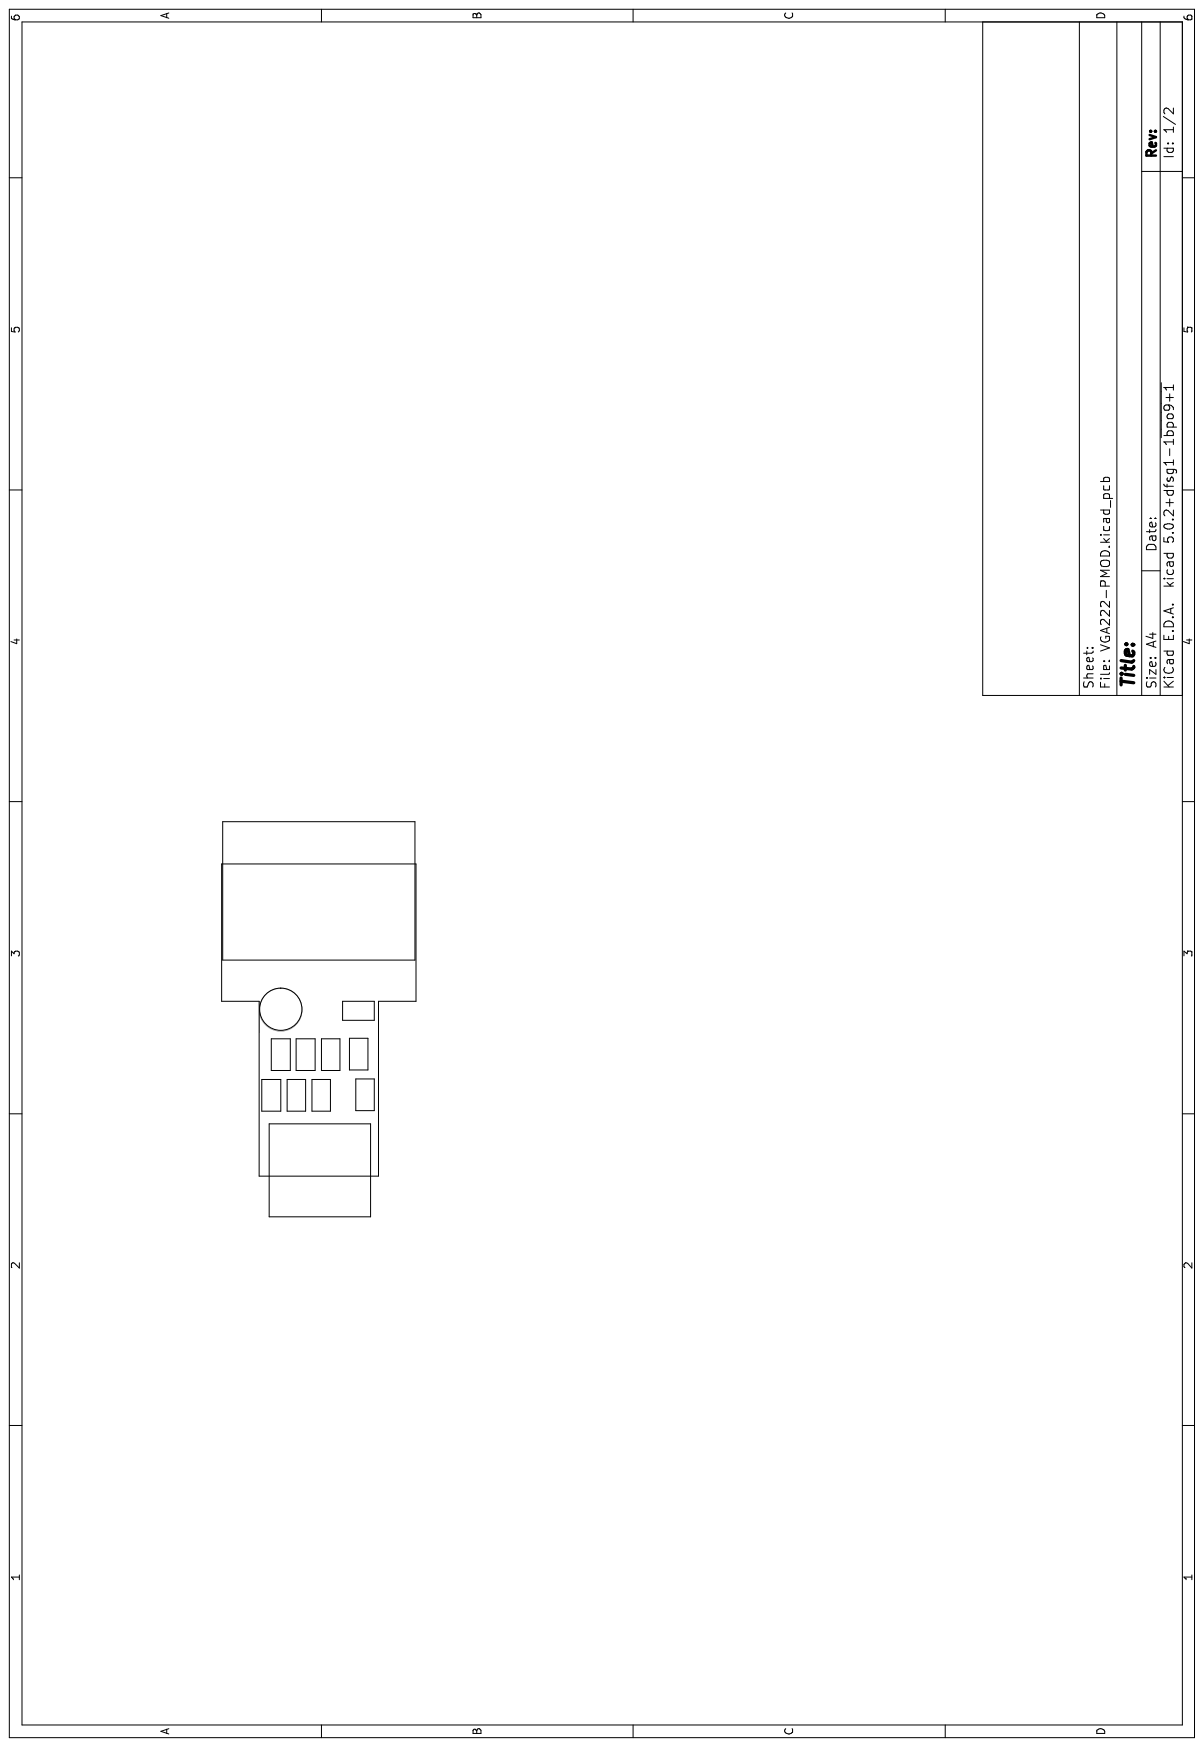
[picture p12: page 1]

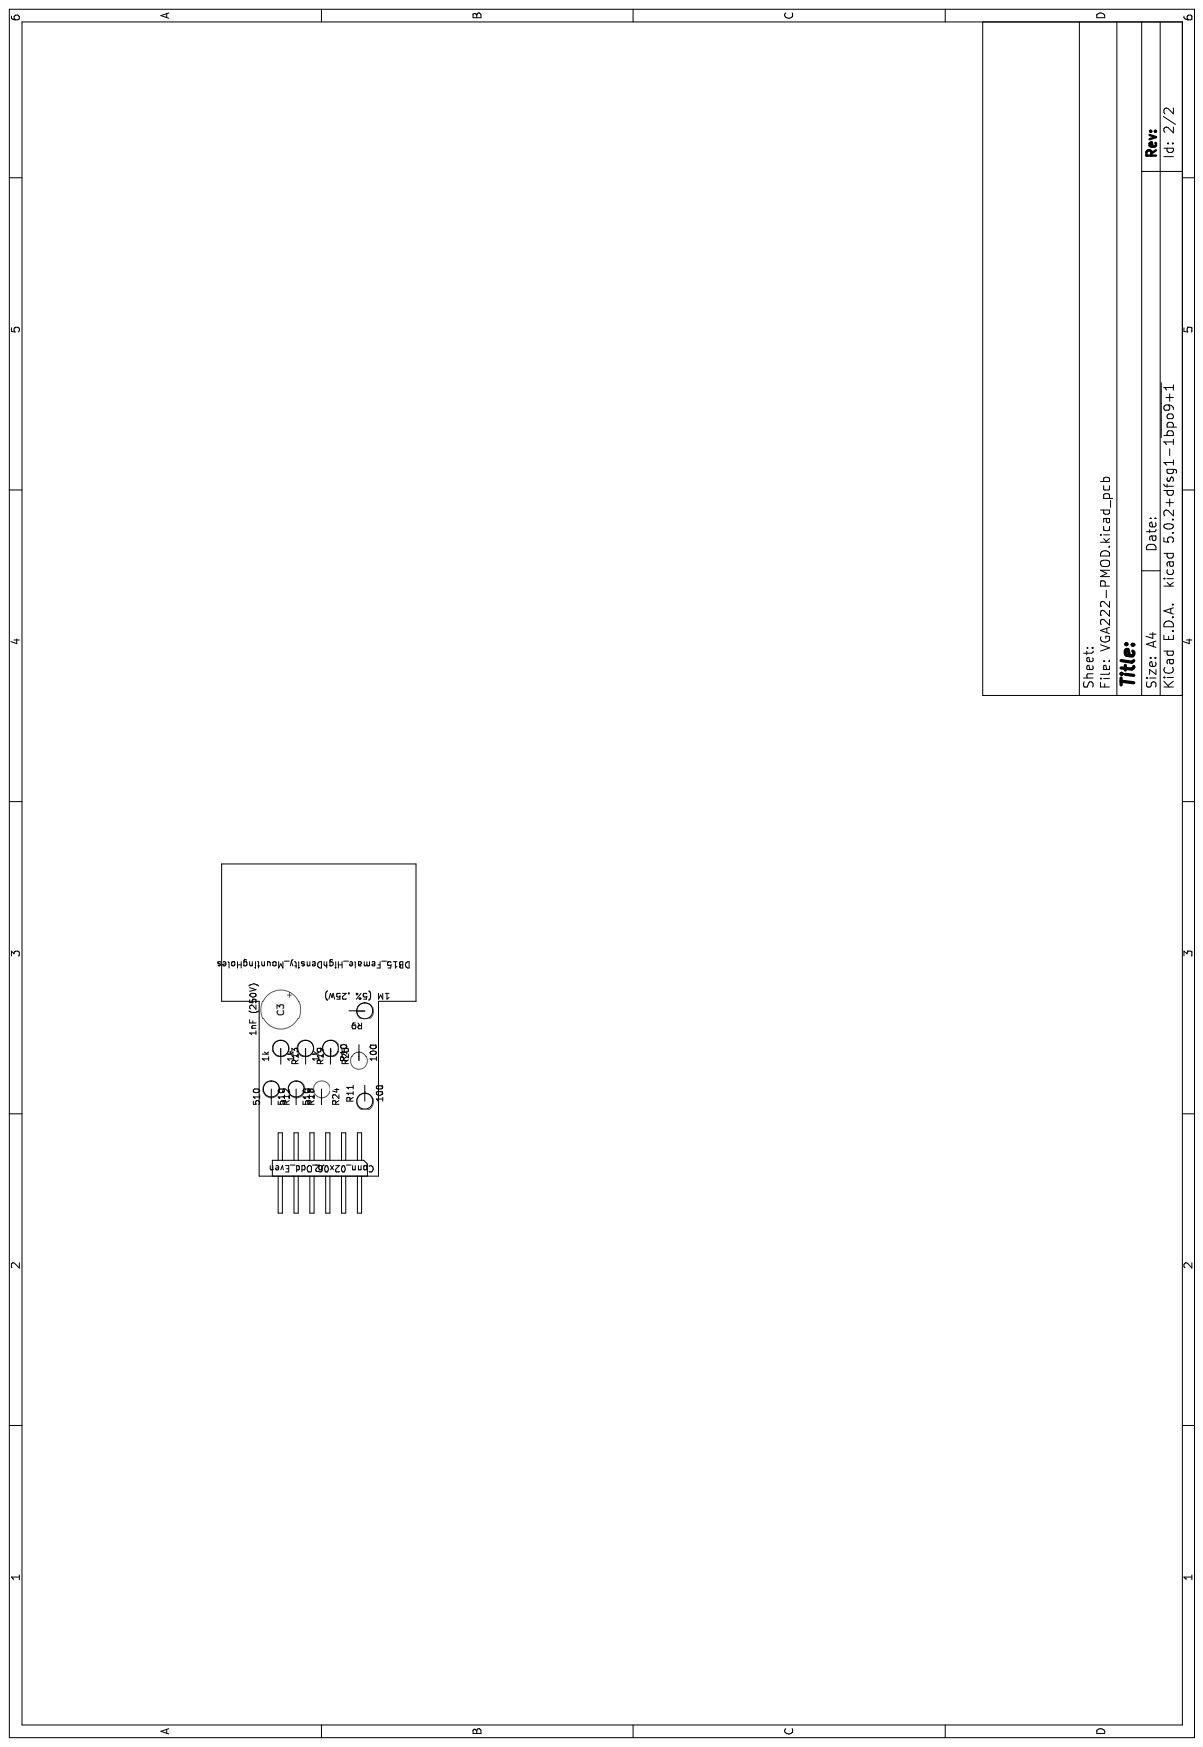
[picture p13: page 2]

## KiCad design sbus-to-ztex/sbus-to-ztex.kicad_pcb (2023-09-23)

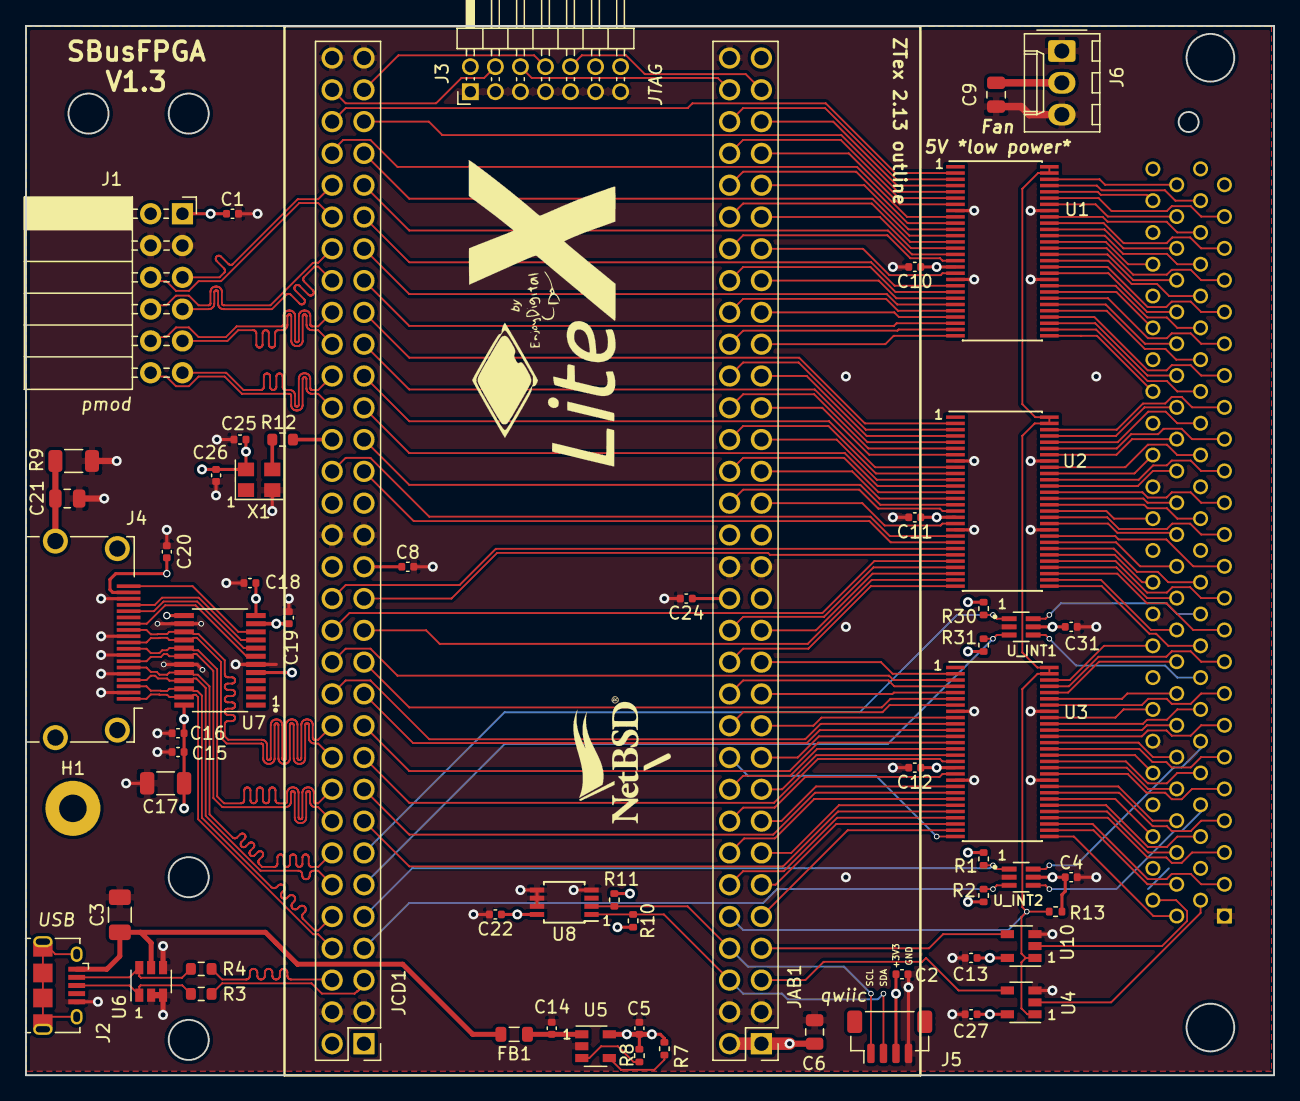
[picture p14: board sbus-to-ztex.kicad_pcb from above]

Board: 4 copper layers, 99.7 x 83.8 mm, 64 parts (1 on the bottom side), 199 nets.

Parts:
C1, C2: 100nF; C_0402_1005Metric
C3: 100uF 1206 (officially 150 uF ? could be >= 100 u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; C_1206_3216Metric
C4, C5, C8, C10, C11, C12, C13, C14, C15, C18, C19, C20, C24, C25, C27, C31: 100nF 0402; C_0402_1005Metric
C6, C9: 47uF 0805; C_0805_2012Metric
C16, C22, C26: 10nF 0402; C_0402_1005Metric
C17: 47uF 10V 1206; C_1206_3216Metric
C21: 10nF 1kV 0805; C_0805_2012Metric
FB1: Ferrite_Bead_Small; L_0805_2012Metric
GRAPHIC1: LogoLitex; litex_logo
GRAPHIC2: LogoNetBSD; netbsd_logo
H1: MountingHole_Pad; MountingHole_2.2mm_M2_Pad
J1: A2541HWR-2x6P (Pmod 2x6 F R); PinSocket_2x06_P2.54mm_Horizontal
J2: 10118194-0001LF (USB micro-B); USB_Micro-B_Amphenol_10118194_Horizontal
J3: Conn_02x07_Odd_Even; PinHeader_2x07_P2.00mm_Horizontal_For_SeeedStudio
J4: 10029449-111RLF (HDMI A); HDMI_A_Amphenol_10029449-111
J5: Conn_01x04_Male; JST_SH_BM04B-SRSS-TB_1x04-1MP_P1.00mm_Vertical
J6: Conn_01x03_Male; Molex_KK-254_AE-6410-03A_1x03_P2.54mm_Vertical
JAB1: ZTEX_AB-ztex_AB; PinHeader_2x32_P2.54mm_Vertical_For_SeeedStudio
JCD1: ZTEX_CD-ztex_CD; PinHeader_2x32_P2.54mm_Vertical_For_SeeedStudio
R1, R2, R7, R8, R13, R30, R31: 10k; R_0402_1005Metric
R3, R4, R12: 27; R_0603_1608Metric
R9: 1M 500V 1206; R_1206_3216Metric
R10, R11: 5.6k; R_0402_1005Metric
SBus1: SBus; FCN-234P096-GY
U1, U2, U3: SN74CB3T16211DGGR; TSSOP-56_6.1x14mm_P0.5mm_For_SeeedStudio
U4, U10: 74CB3T1G125; SOT-23-5
U5: TPS2051CDBV; SOT-23-5
U6: SRV05-4; SOT-23-6
U7: TPD12S016PWR; SOP65P640X120-24N
U8: PCT2075DP; TSSOP-8_3x3mm_P0.65mm_ForSeeedStudio
U_INT1, U_INT2: 74LVC2G07; SOT65P210X110-6N
X1: ASE-xxxMHz; Oscillator_SMD_Abracon_ASE-4Pin_3.2x2.5mm

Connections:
+3V3: C1.1, C2.1, C4.1, C8.1, C10.1, C11.1, C12.1, C13.1, C15.1, C16.1, C17.1, C18.1, C22.1, C24.1, C25.1, C26.1, C27.1, C31.1, J1.1, J1.2, J5.3, JAB1.29, JAB1.30, JAB1.33, JAB1.34, JCD1.31, JCD1.32, JCD1.35, JCD1.36, R1.1, R2.1, R10.2, R11.2, R13.1, R30.1, R31.1, U1.17, U2.17, U3.17, U4.5, U7.5, U7.12, U7.24, U8.8, U10.5, U_INT1.5, U_INT2.5, X1.4
+5V: C5.1, C6.1, C9.1, C19.1, J6.2, JAB1.1, JAB1.2, R7.2, R8.2, SBus1.56, SBus1.64, SBus1.72, SBus1.80, SBus1.88, U5.5, U7.11
/B2B/JTAG_TCK: J3.6, JAB1.62
/B2B/JTAG_TDI: J3.10, JAB1.61
/B2B/JTAG_TDO: J3.8, JCD1.61
/B2B/JTAG_TMS: J3.4, JCD1.62
/B2B/JTAG_VIO: J3.2, JAB1.63
/USB/USB_D+: J2.3, R3.1, U6.1
/USB/USB_D-: J2.2, R4.1, U6.6
/USB/USB_EN: R7.1, U5.4
/USB/USB_FLT: R8.1, U5.3
/USB/VBus: C14.1, FB1.1, U5.1
/USB/VBus_USB0: C3.1, FB1.2, J2.1, U6.5
/hdmi/HDMI_5V: C20.1, J4.18, U7.13
/hdmi/cec_b: J4.13, U7.7
/hdmi/hpd_b: J4.19, U7.10
/hdmi/scl_b: J4.15, U7.8
/hdmi/sda_b: J4.16, U7.9
CLK_54_000: JCD1.40, R12.1
GND: C1.2, C2.2, C3.2, C4.2, C5.2, C6.2, C8.2, C9.2, C10.2, C11.2, C12.2, C13.2, C14.2, C15.2, C16.2, C17.2, C18.2, C19.2, C20.2, C21.2, C22.2, C24.2, C25.2, C26.2, C27.2, C31.2, J1.3, J1.4, J2.5, J3.1, J3.3, J3.5, J3.7, J3.9, J3.11, J3.13, J4.2, J4.5, J4.8, J4.11, J4.17, J5.4, J6.1, J6.3, JAB1.3, JAB1.4, JAB1.31, JAB1.32, JAB1.64, JCD1.3, JCD1.4, JCD1.33, JCD1.34, JCD1.63, JCD1.64, R9.2, SBus1.01, SBus1.52, SBus1.60, SBus1.68, SBus1.76, SBus1.84, SBus1.92, U1.8, U1.19, U1.38, U1.49, U2.8, U2.19, U2.38, U2.49, U3.8, U3.19, U3.38, U3.49, U4.3, U5.2, U6.2, U6.3, U6.4, U7.6, U7.14, U7.19, U8.4, U8.5, U8.6, U8.7, U10.3, U_INT1.2, U_INT2.2, X1.2
HDMI_CLK+: J4.10, JCD1.20, U7.16
HDMI_CLK-: J4.12, JCD1.22, U7.15
HDMI_D0+: J4.7, JCD1.16, U7.18
HDMI_D0-: J4.9, JCD1.18, U7.17
HDMI_D1+: J4.4, JCD1.12, U7.21
HDMI_D1-: J4.6, JCD1.14, U7.20
HDMI_D2+: J4.1, JCD1.8, U7.23
HDMI_D2-: J4.3, JCD1.10, U7.22
I2C0_SCL: J5.1, JAB1.8, R11.1, U8.2
I2C0_SDA: J5.2, JAB1.6, R10.1, U8.1
unnamed: R12.2, X1.3
PMOD-56+: J1.6, JCD1.54
PMOD-56-: J1.5, JCD1.56
PMOD-78+: J1.8, JCD1.52
PMOD-78-: J1.7, JCD1.50
PMOD-910+: J1.10, JCD1.48
PMOD-910-: J1.9, JCD1.46
PMOD-1112+: J1.12, JCD1.42
PMOD-1112-: J1.11, JCD1.44
SBUS_3V3_ACK[0]*: JAB1.48, U1.24
SBUS_3V3_ACK[1]*: JCD1.55, U1.15
SBUS_3V3_ACK[2]*: JAB1.57, U1.7
SBUS_3V3_AS*: JAB1.9, U3.27
SBUS_3V3_BG*: JAB1.7, U10.4
SBUS_3V3_BR*: JAB1.5, U4.4
SBUS_3V3_CLK: JAB1.20, U3.28
SBUS_3V3_D[00]: JAB1.12, U3.25
SBUS_3V3_D[01]: JCD1.15, U3.24
SBUS_3V3_D[02]: JAB1.13, U3.23
SBUS_3V3_D[03]: JAB1.14, U3.22
SBUS_3V3_D[04]: JCD1.17, U3.21
SBUS_3V3_D[05]: JAB1.15, U3.20
SBUS_3V3_D[06]: JAB1.16, U3.18
SBUS_3V3_D[07]: JCD1.19, U3.16
SBUS_3V3_D[08]: JAB1.17, U3.15
SBUS_3V3_D[09]: JAB1.18, U3.14
SBUS_3V3_D[10]: JCD1.21, U3.13
SBUS_3V3_D[11]: JAB1.19, U3.12
SBUS_3V3_D[12]: JCD1.23, U3.11
SBUS_3V3_D[13]: JCD1.24, U3.10
SBUS_3V3_D[14]: JAB1.21, U3.9
SBUS_3V3_D[15]: JAB1.22, U3.7
SBUS_3V3_D[16]: JCD1.25, U3.6
SBUS_3V3_D[17]: JAB1.23, U3.5
SBUS_3V3_D[18]: JAB1.24, U3.4
SBUS_3V3_D[19]: JCD1.26, U3.3
SBUS_3V3_D[20]: JAB1.25, U3.2
SBUS_3V3_D[21]: JAB1.26, U2.28
SBUS_3V3_D[22]: JCD1.27, U2.27
SBUS_3V3_D[23]: JAB1.27, U2.26
SBUS_3V3_D[24]: JAB1.28, U2.25
SBUS_3V3_D[25]: JCD1.28, U2.24
SBUS_3V3_D[26]: JCD1.29, U2.23
SBUS_3V3_D[27]: JCD1.30, U2.22
SBUS_3V3_D[28]: JCD1.37, U2.21
SBUS_3V3_D[29]: JCD1.38, U2.20
SBUS_3V3_D[30]: JAB1.35, U2.18
SBUS_3V3_D[31]: JAB1.36, U2.16
SBUS_3V3_EER*: JAB1.43, U2.4
SBUS_3V3_INT[2]*: JCD1.7, R2.2, U_INT2.3
SBUS_3V3_INT[3]*: JCD1.9, R1.2, U_INT2.1
SBUS_3V3_INT[4]*: JCD1.11, R31.2, U_INT1.3
SBUS_3V3_INT[5]*: JCD1.13, R30.2, U_INT1.1
SBUS_3V3_PA[00]: JAB1.40, U2.10
SBUS_3V3_PA[01]: JAB1.39, U2.11
SBUS_3V3_PA[02]: JAB1.41, U2.7
SBUS_3V3_PA[03]: JCD1.43, U2.9
SBUS_3V3_PA[04]: JCD1.45, U2.5
SBUS_3V3_PA[05]: JAB1.42, U2.6
SBUS_3V3_PA[06]: JCD1.47, U2.2
SBUS_3V3_PA[07]: JAB1.44, U2.3
SBUS_3V3_PA[08]: JAB1.46, U1.27
SBUS_3V3_PA[09]: JAB1.45, U1.28
SBUS_3V3_PA[10]: JAB1.47, U1.25
SBUS_3V3_PA[11]: JCD1.49, U1.26
SBUS_3V3_PA[12]: JAB1.49, U1.22
SBUS_3V3_PA[13]: JCD1.51, U1.23
SBUS_3V3_PA[14]: JCD1.53, U1.20
SBUS_3V3_PA[15]: JAB1.50, U1.21
SBUS_3V3_PA[16]: JAB1.52, U1.16
SBUS_3V3_PA[17]: JAB1.51, U1.18
SBUS_3V3_PA[18]: JAB1.54, U1.13
SBUS_3V3_PA[19]: JAB1.53, U1.14
SBUS_3V3_PA[20]: JAB1.55, U1.11
SBUS_3V3_PA[21]: JCD1.57, U1.12
SBUS_3V3_PA[22]: JCD1.58, U1.9
SBUS_3V3_PA[23]: JAB1.56, U1.10
SBUS_3V3_PA[24]: JCD1.59, U1.5
SBUS_3V3_PA[25]: JAB1.58, U1.6
SBUS_3V3_PA[26]: JAB1.60, U1.3
SBUS_3V3_PA[27]: JAB1.59, U1.4
SBUS_3V3_PPRD: JAB1.38, U2.13
SBUS_3V3_RST*: JCD1.60, U1.2
SBUS_3V3_SEL*: JAB1.11, U3.26
SBUS_3V3_SIZ[0]: JAB1.37, U2.14
SBUS_3V3_SIZ[1]: JCD1.39, U2.15
SBUS_3V3_SIZ[2]: JCD1.41, U2.12
SBUS_5V_ACK[0]*: SBus1.36, U1.33
SBUS_5V_ACK[1]*: SBus1.40, U1.41
SBUS_5V_ACK[2]*: SBus1.44, U1.48
SBUS_5V_AS*: SBus1.51, U3.30
SBUS_5V_BG*: SBus1.50, U10.2
SBUS_5V_BR*: SBus1.02, U4.2
SBUS_5V_CLK: SBus1.49, U3.29
SBUS_5V_D[00]: SBus1.05, U3.32
SBUS_5V_D[01]: SBus1.53, U3.33
SBUS_5V_D[02]: SBus1.06, U3.34
SBUS_5V_D[03]: SBus1.54, U3.35
SBUS_5V_D[04]: SBus1.07, U3.36
SBUS_5V_D[05]: SBus1.55, U3.37
SBUS_5V_D[06]: SBus1.09, U3.39
SBUS_5V_D[07]: SBus1.57, U3.40
SBUS_5V_D[08]: SBus1.10, U3.41
SBUS_5V_D[09]: SBus1.58, U3.42
SBUS_5V_D[10]: SBus1.11, U3.43
SBUS_5V_D[11]: SBus1.59, U3.44
SBUS_5V_D[12]: SBus1.13, U3.45
SBUS_5V_D[13]: SBus1.61, U3.46
SBUS_5V_D[14]: SBus1.14, U3.47
SBUS_5V_D[15]: SBus1.62, U3.48
SBUS_5V_D[16]: SBus1.15, U3.50
SBUS_5V_D[17]: SBus1.63, U3.51
SBUS_5V_D[18]: SBus1.65, U3.52
SBUS_5V_D[19]: SBus1.17, U3.53
SBUS_5V_D[20]: SBus1.66, U3.54
SBUS_5V_D[21]: SBus1.18, U2.29
SBUS_5V_D[22]: SBus1.67, U2.30
SBUS_5V_D[23]: SBus1.19, U2.31
SBUS_5V_D[24]: SBus1.69, U2.32
SBUS_5V_D[25]: SBus1.21, U2.33
SBUS_5V_D[26]: SBus1.70, U2.34
SBUS_5V_D[27]: SBus1.22, U2.35
SBUS_5V_D[28]: SBus1.71, U2.36
SBUS_5V_D[29]: SBus1.23, U2.37
SBUS_5V_D[30]: SBus1.73, U2.39
SBUS_5V_D[31]: SBus1.25, U2.40
SBUS_5V_EER*: SBus1.32, U2.52
SBUS_5V_INT[2]*: SBus1.08, U_INT2.4
SBUS_5V_INT[3]*: SBus1.12, U_INT2.6
SBUS_5V_INT[4]*: SBus1.16, U_INT1.4
SBUS_5V_INT[5]*: SBus1.20, U_INT1.6
SBUS_5V_PA[00]: SBus1.29, U2.46
SBUS_5V_PA[01]: SBus1.77, U2.45
SBUS_5V_PA[02]: SBus1.30, U2.48
SBUS_5V_PA[03]: SBus1.78, U2.47
SBUS_5V_PA[04]: SBus1.31, U2.51
SBUS_5V_PA[05]: SBus1.79, U2.50
SBUS_5V_PA[06]: SBus1.33, U2.54
SBUS_5V_PA[07]: SBus1.81, U2.53
SBUS_5V_PA[08]: SBus1.34, U1.30
SBUS_5V_PA[09]: SBus1.82, U1.29
SBUS_5V_PA[10]: SBus1.35, U1.32
SBUS_5V_PA[11]: SBus1.83, U1.31
SBUS_5V_PA[12]: SBus1.37, U1.35
SBUS_5V_PA[13]: SBus1.85, U1.34
SBUS_5V_PA[14]: SBus1.38, U1.37
SBUS_5V_PA[15]: SBus1.86, U1.36
SBUS_5V_PA[16]: SBus1.39, U1.40
SBUS_5V_PA[17]: SBus1.87, U1.39
SBUS_5V_PA[18]: SBus1.41, U1.43
SBUS_5V_PA[19]: SBus1.89, U1.42
SBUS_5V_PA[20]: SBus1.42, U1.45
SBUS_5V_PA[21]: SBus1.90, U1.44
SBUS_5V_PA[22]: SBus1.43, U1.47
SBUS_5V_PA[23]: SBus1.91, U1.46
SBUS_5V_PA[24]: SBus1.45, U1.51
SBUS_5V_PA[25]: SBus1.93, U1.50
SBUS_5V_PA[26]: SBus1.46, U1.53
SBUS_5V_PA[27]: SBus1.94, U1.52
SBUS_5V_PPRD: SBus1.75, U2.43
SBUS_5V_RST*: SBus1.95, U1.54
SBUS_5V_SEL*: SBus1.03, U3.31
SBUS_5V_SIZ[0]: SBus1.26, U2.42
SBUS_5V_SIZ[1]: SBus1.74, U2.41
SBUS_5V_SIZ[2]: SBus1.27, U2.44
SBUS_OE: JAB1.10, R13.2, U1.55, U1.56, U2.55, U2.56, U3.55, U3.56, U4.1, U10.1
SHIELD: C21.1, H1.1, J2.6, J4.SH, R9.1
USBH0_D+: JCD1.5, R3.2
USBH0_D-: JCD1.6, R4.2

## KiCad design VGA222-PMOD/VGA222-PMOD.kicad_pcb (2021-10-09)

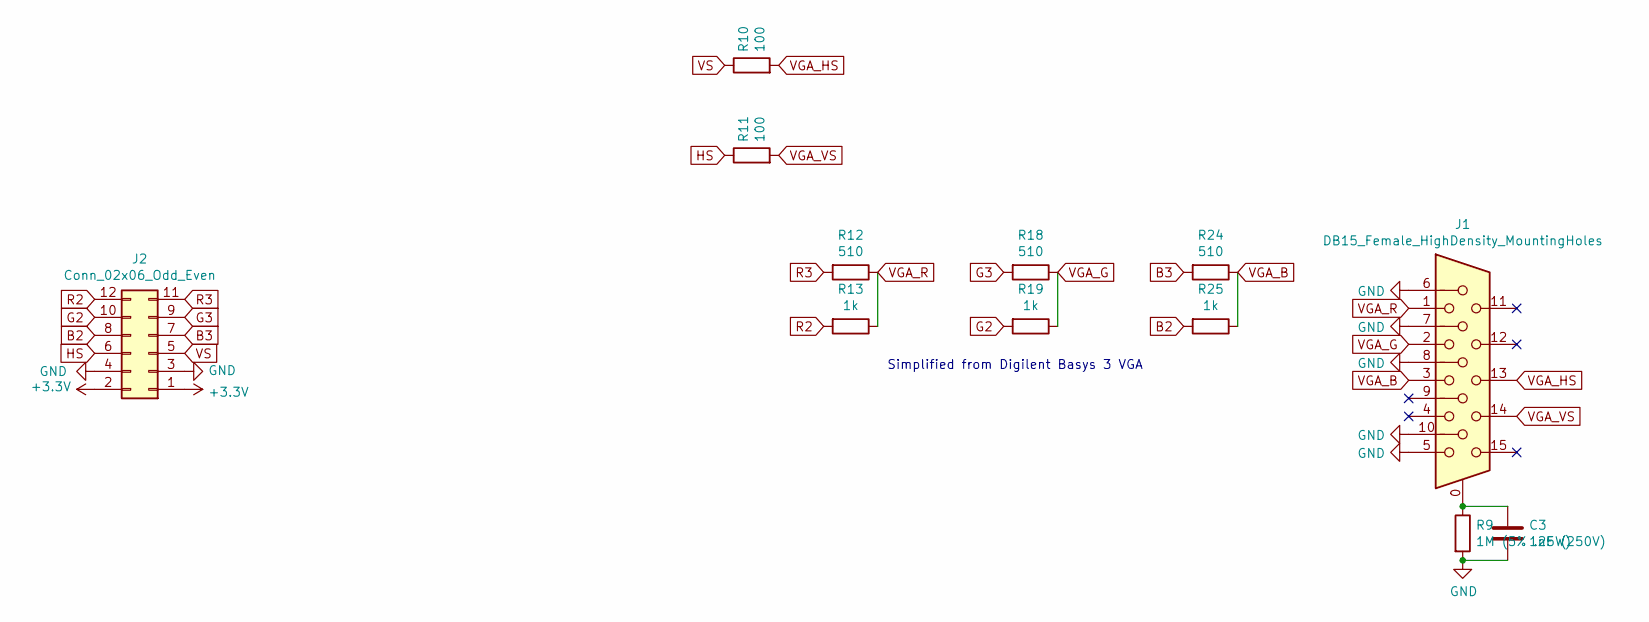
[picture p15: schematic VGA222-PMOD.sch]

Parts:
C3: 1nF (250V); CP_Radial_D6.3mm_P2.50mm; MPN 860021373002
J1: DB15_Female_HighDensity_MountingHoles; L77HDE15SD1CH4RHNVGA; MPN L77HDE15SD1CH4RHNVGA
J2: Conn_02x06_Odd_Even; PinHeader_2x06_P2.54mm_Horizontal; MPN A2541WR-2x6P
R9: 1M (5% .25W); R_Axial_DIN0207_L6.3mm_D2.5mm_P2.54mm_Vertical; MPN MFR50SFTE52-1M
R10, R11: 100; R_Axial_DIN0207_L6.3mm_D2.5mm_P2.54mm_Vertical; MPN-ALT MFR-25FTE52-100R
R12, R18, R24: 510; R_Axial_DIN0207_L6.3mm_D2.5mm_P2.54mm_Vertical; MPN MFR-25FTE52-510R
R13, R19, R25: 1k; R_Axial_DIN0207_L6.3mm_D2.5mm_P2.54mm_Vertical; MPN-ALT MFR-25FTE52-1K

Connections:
+3V3: J2.1, J2.2
B2: J2.8, R25.2
B3: J2.7, R24.2
G2: J2.10, R19.2
G3: J2.9, R18.2
GND: C3.2, J1.5, J1.6, J1.7, J1.8, J1.10, J2.3, J2.4, R9.2
HS: J2.6, R11.1
unnamed: C3.1, J1.0, R9.1
R2: J2.12, R13.2
R3: J2.11, R12.2
VGA_B: J1.3, R24.1, R25.1
VGA_G: J1.2, R18.1, R19.1
VGA_HS: J1.13, R10.2
VGA_R: J1.1, R12.1, R13.1
VGA_VS: J1.14, R11.2
VS: J2.5, R10.1

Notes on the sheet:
Simplified from Digilent Basys 3 VGA

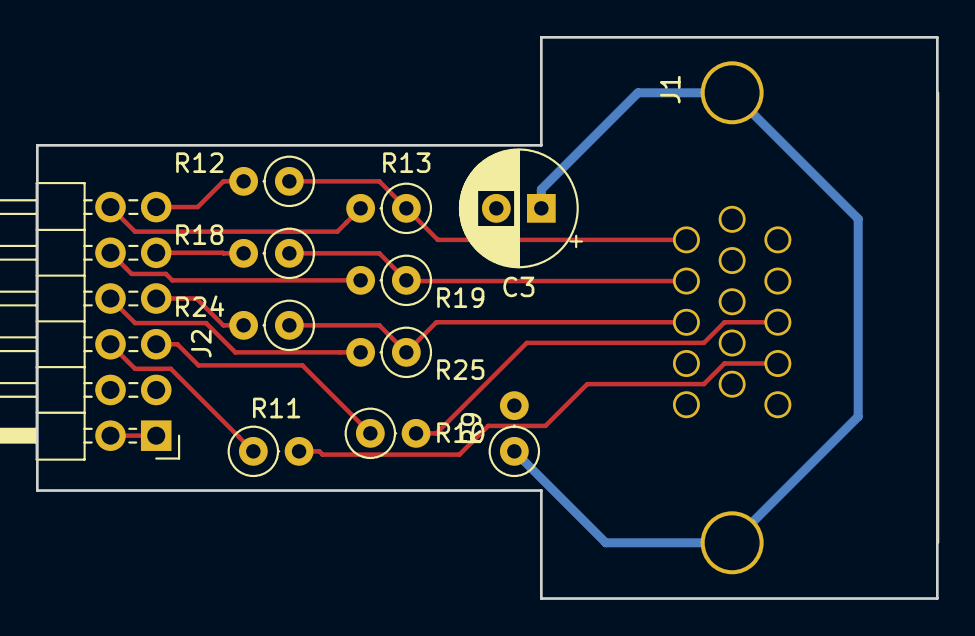
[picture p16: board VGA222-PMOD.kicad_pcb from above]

Board: 2 copper layers, 50.0 x 31.2 mm, 12 parts (0 on the bottom side), 16 nets.

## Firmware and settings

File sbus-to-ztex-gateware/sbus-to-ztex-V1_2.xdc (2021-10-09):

# !!! Constraint files are application specific !!!
# !!!          This is a template only          !!!

# on-board signals

# CLKOUT/FXCLK 
create_clock -name fxclk_in -period 20.833 [get_ports fxclk_in]
set_property PACKAGE_PIN P15 [get_ports fxclk_in]
set_property IOSTANDARD LVCMOS33 [get_ports fxclk_in]

# IFCLK 
#create_clock -name ifclk_in -period 20.833 [get_ports ifclk_in]
#set_property PACKAGE_PIN P17 [get_ports ifclk_in]
#set_property IOSTANDARD LVCMOS33 [get_ports ifclk_in]

set_property CONFIG_VOLTAGE 3.3 [current_design]
set_property CFGBVS VCCO [current_design]
set_property BITSTREAM.CONFIG.CONFIGRATE 66 [current_design]  
set_property BITSTREAM.CONFIG.SPI_32BIT_ADDR No [current_design]
set_property BITSTREAM.CONFIG.SPI_BUSWIDTH 2 [current_design]
set_property BITSTREAM.GENERAL.COMPRESS true [current_design] 

#set_property PACKAGE_PIN M16 [get_ports {PB[0]}]  		;# PB0/FD0
#set_property IOSTANDARD LVCMOS33 [get_ports {PB[0]}]

#set_property PACKAGE_PIN L16 [get_ports {PB[1]}]  		;# PB1/FD1
#set_property IOSTANDARD LVCMOS33 [get_ports {PB[1]}]

#set_property PACKAGE_PIN L14 [get_ports {PB[2]}]  		;# PB2/FD2
#set_property IOSTANDARD LVCMOS33 [get_ports {PB[2]}]

#set_property PACKAGE_PIN M14 [get_ports {PB[3]}]  		;# PB3/FD3
#set_property IOSTANDARD LVCMOS33 [get_ports {PB[3]}]

#set_property PACKAGE_PIN L18 [get_ports {PB[4]}]  		;# PB4/FD4
#set_property IOSTANDARD LVCMOS33 [get_ports {PB[4]}]

#set_property PACKAGE_PIN M18 [get_ports {PB[5]}]  		;# PB5/FD5
#set_property IOSTANDARD LVCMOS33 [get_ports {PB[5]}]

#set_property PACKAGE_PIN R12 [get_ports {PB[6]}]  		;# PB6/FD6
#set_property IOSTANDARD LVCMOS33 [get_ports {PB[6]}]

#set_property PACKAGE_PIN R13 [get_ports {PB[7]}]  		;# PB7/FD7
#set_property IOSTANDARD LVCMOS33 [get_ports {PB[7]}]


#set_property PACKAGE_PIN T9 [get_ports {PD[0]}]  		;# PD0/FD8
#set_property IOSTANDARD LVCMOS33 [get_ports {PD[0]}]

#set_property PACKAGE_PIN V10 [get_ports {PD[1]}]  		;# PD1/FD9
#set_property IOSTANDARD LVCMOS33 [get_ports {PD[1]}]

#set_property PACKAGE_PIN U11 [get_ports {PD[2]}]  		;# PD2/FD10
#set_property IOSTANDARD LVCMOS33 [get_ports {PD[2]}]

#set_property PACKAGE_PIN V11 [get_ports {PD[3]}]  		;# PD3/FD11
#set_property IOSTANDARD LVCMOS33 [get_ports {PD[3]}]

#set_property PACKAGE_PIN V12 [get_ports {PD[4]}]  		;# PD4/FD12
#set_property IOSTANDARD LVCMOS33 [get_ports {PD[4]}]

#set_property PACKAGE_PIN U13 [get_ports {PD[5]}]  		;# PD5/FD13
#set_property IOSTANDARD LVCMOS33 [get_ports {PD[5]}]

#set_property PACKAGE_PIN U14 [get_ports {PD[6]}]  		;# PD6/FD14
#set_property IOSTANDARD LVCMOS33 [get_ports {PD[6]}]

#set_property PACKAGE_PIN V14 [get_ports {PD[7]}]  		;# PD7/FD15
#set_property IOSTANDARD LVCMOS33 [get_ports {PD[7]}]


#set_property PACKAGE_PIN R15 [get_ports {PA[0]}]  		;# PA0/INT0#
#set_property IOSTANDARD LVCMOS33 [get_ports {PA[0]}]

#set_property PACKAGE_PIN T15 [get_ports {PA[1]}]  		;# PA1/INT1#
#set_property IOSTANDARD LVCMOS33 [get_ports {PA[1]}]

#set_property PACKAGE_PIN T14 [get_ports {PA[2]}]  		;# PA2/SLOE
#set_property IOSTANDARD LVCMOS33 [get_ports {PA[2]}]

#set_property PACKAGE_PIN T13 [get_ports {PA[3]}]  		;# PA3/WU2
#set_property IOSTANDARD LVCMOS33 [get_ports {PA[3]}]

#set_property PACKAGE_PIN R11 [get_ports {PA[4]}]  		;# PA4/FIFOADR0
#set_property IOSTANDARD LVCMOS33 [get_ports {PA[4]}]

#set_property PACKAGE_PIN T11 [get_ports {PA[5]}]  		;# PA5/FIFOADR1
#set_property IOSTANDARD LVCMOS33 [get_ports {PA[5]}]

#set_property PACKAGE_PIN R10 [get_ports {PA[6]}]  		;# PA6/PKTEND
#set_property IOSTANDARD LVCMOS33 [get_ports {PA[6]}]

#set_property PACKAGE_PIN T10 [get_ports {PA[7]}]  		;# PA7/FLAGD/SLCS#
#set_property IOSTANDARD LVCMOS33 [get_ports {PA[7]}]


#set_property PACKAGE_PIN R17 [get_ports {PC[0]}]  		;# PC0/GPIFADR0
#set_property IOSTANDARD LVCMOS33 [get_ports {PC[0]}]

#set_property PACKAGE_PIN R18 [get_ports {PC[1]}]  		;# PC1/GPIFADR1
#set_property IOSTANDARD LVCMOS33 [get_ports {PC[1]}]

#set_property PACKAGE_PIN P18 [get_ports {PC[2]}]  		;# PC2/GPIFADR2
#set_property IOSTANDARD LVCMOS33 [get_ports {PC[2]}]

#set_property PACKAGE_PIN P14 [get_ports {PC[3]}]  		;# PC3/GPIFADR3
#set_property IOSTANDARD LVCMOS33 [get_ports {PC[3]}]

#set_property PACKAGE_PIN K18 [get_ports {FLASH_DO}]  		;# PC4/GPIFADR4
#set_property IOSTANDARD LVCMOS33 [get_ports {FLASH_DO}]

#set_property PACKAGE_PIN L13 [get_ports {FLASH_CS}]  		;# PC5/GPIFADR5
#set_property IOSTANDARD LVCMOS33 [get_ports {FLASH_CS}]

#set_property PACKAGE_PIN E9 [get_ports {FLASH_CLK}]  		;# PC6/GPIFADR6
#set_property IOSTANDARD LVCMOS33 [get_ports {FLASH_CLK}]

#set_property PACKAGE_PIN K17 [get_ports {FLASH_DI}]  		;# PC7/GPIFADR7
#set_property IOSTANDARD LVCMOS33 [get_ports {FLASH_DI}]


#set_property PACKAGE_PIN P10 [get_ports {PE[0]}]  		;# PE0/T0OUT
#set_property IOSTANDARD LVCMOS33 [get_ports {PE[0]}]

#set_property PACKAGE_PIN P7 [get_ports {PE[1]}]  		;# PE1/T1OUT
#set_property IOSTANDARD LVCMOS33 [get_ports {PE[1]}]
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

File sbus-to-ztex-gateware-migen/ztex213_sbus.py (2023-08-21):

#
# This file is part of LiteX-Boards.
#
# Support for the ZTEX USB-FGPA Module 2.13:
# <https://www.ztex.de/usb-fpga-2/usb-fpga-2.13.e.html>
# With (no-so-optional) expansion, either the ZTEX Debug board:
# <https://www.ztex.de/usb-fpga-2/debug.e.html>
# Or the SBusFPGA adapter board:
# <https://github.com/rdolbeau/SBusFPGA>
#
# Copyright (c) 2015 Yann Sionneau <yann.sionneau@gmail.com>
# Copyright (c) 2015-2019 Florent Kermarrec <florent@enjoy-digital.fr>
# Copyright (c) 2020-2021 Romain Dolbeau <romain@dolbeau.org>
# SPDX-License-Identifier: BSD-2-Clause

from litex.build.generic_platform import *
from litex.build.xilinx import XilinxPlatform
from litex.build.openocd import OpenOCD

# IOs ----------------------------------------------------------------------------------------------

# FPGA daughterboard I/O

_io = [
    ## 48 MHz clock reference
    ("clk48", 0, Pins("P15"), IOStandard("LVCMOS33")),
    ## embedded 256 MiB DDR3 DRAM
    ("ddram", 0,
        Subsignal("a", Pins("C5 B6 C7 D5 A3 E7 A4 C6", "A6 D8 B2 A5 B3 B7"),
            IOStandard("SSTL135")),
        Subsignal("ba",    Pins("E5 A1 E6"), IOStandard("SSTL135")),
        Subsignal("ras_n", Pins("E3"), IOStandard("SSTL135")),
        Subsignal("cas_n", Pins("D3"), IOStandard("SSTL135")),
        Subsignal("we_n",  Pins("D4"), IOStandard("SSTL135")),
#        Subsignal("cs_n",  Pins(""), IOStandard("SSTL135")),
        Subsignal("dm", Pins("G1 G6"), IOStandard("SSTL135")),
        Subsignal("dq", Pins(
            "H1 F1 E2 E1 F4 C1 F3 D2",
            "G4 H5 G3 H6 J2 J3 K1 K2"),
            IOStandard("SSTL135"),
            Misc("IN_TERM=UNTUNED_SPLIT_40")),
        Subsignal("dqs_p", Pins("H2 J4"),
            IOStandard("DIFF_SSTL135"),
            Misc("IN_TERM=UNTUNED_SPLIT_40")),
        Subsignal("dqs_n", Pins("G2 H4"),
            IOStandard("DIFF_SSTL135"),
            Misc("IN_TERM=UNTUNED_SPLIT_40")),
        Subsignal("clk_p", Pins("C4"), IOStandard("DIFF_SSTL135")),
        Subsignal("clk_n", Pins("B4"), IOStandard("DIFF_SSTL135")),
        Subsignal("cke",   Pins("B1"), IOStandard("SSTL135")),
        Subsignal("odt",   Pins("F5"), IOStandard("SSTL135")),
        Subsignal("reset_n", Pins("J5"), IOStandard("SSTL135")),
        Misc("SLEW=FAST"),
    ),
]

# SBusFPGA I/O

_sbus_io_v1_0 = [
    ## leds on the SBus board
    ("user_led", 0, Pins("U8"),  IOStandard("lvcmos33")), #LED0
    ("user_led", 1, Pins("U7"),  IOStandard("lvcmos33")), #LED1
    ("user_led", 2, Pins("U6"),  IOStandard("lvcmos33")), #LED2
    ("user_led", 3, Pins("T8"),  IOStandard("lvcmos33")), #LED3
    ("user_led", 4, Pins("P4"),  IOStandard("lvcmos33")), #LED4
    ("user_led", 5, Pins("P3"),  IOStandard("lvcmos33")), #LED5
    ("user_led", 6, Pins("T1"),  IOStandard("lvcmos33")), #LED6
    ("user_led", 7, Pins("R1"),  IOStandard("lvcmos33")), #LED7
    #("user_led", 8, Pins("U1"),  IOStandard("lvcmos33")), #SBUS_DATA_OE_LED
    #("user_led", 9, Pins("T3"),  IOStandard("lvcmos33")), #SBUS_DATA_OE_LED_2
    ## serial header for console
    ("serial", 0,
     Subsignal("tx", Pins("V9")), # FIXME: might be the other way round
     Subsignal("rx", Pins("U9")),
     IOStandard("LVCMOS33")
    ),
    ## sdcard connector
    ("spisdcard", 0,
        Subsignal("clk",  Pins("R8")),
        Subsignal("mosi", Pins("T5"), Misc("PULLUP True")),
        Subsignal("cs_n", Pins("V6"), Misc("PULLUP True")),
        Subsignal("miso", Pins("V5"), Misc("PULLUP True")),
        Misc("SLEW=FAST"),
        IOStandard("LVCMOS33"),
    ),
    ("sdcard", 0,
        Subsignal("data", Pins("V5 V4 V7 V6"), Misc("PULLUP True")),
        Subsignal("cmd",  Pins("T5"), Misc("PULLUP True")),
        Subsignal("clk",  Pins("R8")),
        #Subsignal("cd",   Pins("V6")),
        Misc("SLEW=FAST"),
        IOStandard("LVCMOS33"),
    ),
]

_sbus_io_v1_2 = [
    ## leds on the SBus board
    ## serial header for console
    ("serial", 0,
     Subsignal("tx", Pins("V9")), # FIXME: might be the other way round
     Subsignal("rx", Pins("U9")),
     IOStandard("LVCMOS33")
    ),
    ## sdcard connector
    ("spisdcard", 0,
        Subsignal("clk",  Pins("R8")),
        Subsignal("mosi", Pins("T5"), Misc("PULLUP True")),
        Subsignal("cs_n", Pins("V6"), Misc("PULLUP True")),
        Subsignal("miso", Pins("V5"), Misc("PULLUP True")),
        Misc("SLEW=FAST"),
        IOStandard("LVCMOS33"),
    ),
    ("sdcard", 0,
        Subsignal("data", Pins("V5 V4 V7 V6"), Misc("PULLUP True")),
        Subsignal("cmd",  Pins("T5"), Misc("PULLUP True")),
        Subsignal("clk",  Pins("R8")),
        #Subsignal("cd",   Pins("V6")),
        Misc("SLEW=FAST"),
        IOStandard("LVCMOS33"),
    ),
    ## USB
    ("usb", 0,
     Subsignal("dp", Pins("U8")),
     Subsignal("dm", Pins("U7")),
     IOStandard("LVCMOS33"))
]

_sbus_io_v1_3 = [
    ## USB
    ("usb", 0,
     Subsignal("dp", Pins("U9")),
     Subsignal("dm", Pins("V9")),
     IOStandard("LVCMOS33")),
    # HDMI
    ("hdmi", 0,
        Subsignal("clk_p",   Pins("U4"), IOStandard("TMDS_33")),
        Subsignal("clk_n",   Pins("U3"), IOStandard("TMDS_33")),
        Subsignal("data0_p", Pins("T5"), IOStandard("TMDS_33")),
        Subsignal("data0_n", Pins("T4"), IOStandard("TMDS_33")), 
        Subsignal("data1_p", Pins("V5"), IOStandard("TMDS_33")),
        Subsignal("data1_n", Pins("V4"), IOStandard("TMDS_33")),
        Subsignal("data2_p", Pins("V7"), IOStandard("TMDS_33")),
        Subsignal("data2_n", Pins("V6"), IOStandard("TMDS_33")),
        #Subsignal("hpd",     Pins(""), IOStandard("LVCMOS33")),
        #Subsignal("sda",     Pins(""), IOStandard("LVCMOS33")),
        #Subsignal("scl",     Pins(""), IOStandard("LVCMOS33")),
        #Subsignal("cec",     Pins(""), IOStandard("LVCMOS33")),
    ),
    ("i2c", 0,
     Subsignal("scl", Pins("J17")),
     Subsignal("sda", Pins("J18")),
     IOStandard("LVCMOS33")),
    ## extra 54 MHz clock reference
    ("clk54", 0, Pins("N5"), IOStandard("LVCMOS33")),
]
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

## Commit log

2020-12-13 Add the sbus-to-zex adapter board
    [B2B.sch, Backplate.scad, Backplate.stl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]
2020-12-13 NetBSD prototype driver
2020-12-13 NetBSD test code for prototype driver
2020-12-16 LEDs show that the board has been probed
2020-12-16 change ROM 'LEDs show that the board has been probed'
2020-12-16 add some extra registers for potential DMA
2020-12-17 ultra-preliminary support for a bus master DMA)
2020-12-18 basic DMA support
2020-12-18 12 bits of blocks in GCM DMA
2020-12-18 add soe rigidity
    [Backplate.scad, Backplate.stl]
2020-12-18 larger DMA burst (Burst16 disabled, as it doesn't work on the SS20, presumably hitting the limit of the 'up-burst-sizes' attribute https://mail-index.netbsd.org/port-sparc/2020/12/18/msg002291.html)
2020-12-19 unify LED register with others
2020-12-21 switch driver code to basic aes128-cbc support, where openssl and devcrypto are in agreement
2020-12-22 DMA busmaster AES-128-CBC
2021-01-03 try multi-sessions; there could be a race condition for keys, and device is too busy leading to failure...
2021-01-04 make AES asynchronous behind a couple FIFOs, now running at 120 MHz
2021-01-09 split AES DMA in two control registers (for future pipelining?)
2021-01-09 DMA for cbc decrypt
2021-01-09 new device name, trying to figure out how to have siblings device in the PROM
2021-01-09 PROM with a second device (not yet in HW), by abusing the tokenizer a bit (OF doesn't behave as OBP2 for siblings)
2021-01-09 Add a secondary driver for a pretend-trng (it's a prng at this stage, the trng I found won't synthesize)
2021-01-09 have a fisrst go at RDOL,sdcard (nor working) as a third device with the XESS sd-card controller.
2021-01-09 split DMA CTRL/ADDR to one per feature (GCM_R, AES_R, AES_W)
2021-01-10 can read some blocks from sd-card, but then something fails and the wrapper won't acknowledge the rd_addr handshake :-(
    [sbus-to-ztex.xdc]
2021-01-10 I|O -> IO for master
    [signals.xlsx]
2021-01-16 switch to different sdcard controller, still not working
2021-01-17 nothing doing, SPI-mode SD won't work reliably :-(
    [sbus-to-ztex.xdc]
2021-03-16 save current status; can read label but not yet mount a partition...
2021-03-21 FAT now mount RO, to be tested more thoroughly
2021-06-15 fix wishbone.sel, now the PROM can control the LEDs :-)
2021-06-19 not working, the DMA seems to fails at frame 3...
2021-06-20 not yet working , DMA very suspicious, at least interrupt seems to propagate...
2021-06-21 Still very wonkey, DMA burning cycles
2021-06-25 DMA supports byte & hword (needed), identify devices but unstable
2021-06-26 tentative USB schematic (unsonnected)
    [sbus-to-ztex.sch, usb.sch]
2021-06-30 Commit first go at v1.2
    [B2B.sch, blinkey.sch, sbus-to-ztex.csv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]
2021-06-30 Commit first go at v1.2 (updated BOM generator)
2021-06-30 fix footprints for SeeedStudio DRC results
    [B2B.sch, blinkey.sch, sbus-to-ztex.kicad_pcb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]
2021-07-01 update some MPN w/ SeeedStudio replacement
    [B2B.sch, blinkey.sch, sbus-to-ztex.csv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]
2021-07-02 more stuff
    [sbus-to-ztex.kicad_pcb]
2021-07-02 add a pwr header (for e.g. non-pwm fan)
    [blinkey.sch, sbus-to-ztex.csv, sbus-to-ztex.kicad_pcb]
2021-07-03 more up-to-date
    [B2B.sch, blinkey.sch, sbus-to-ztex.csv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]
2021-07-14 driver to initialize the SDRAM (should be done in the PROM, but easier in C...)
2021-07-14 fix export for driver
2021-07-17 access the SDRAM using a custom DMA; unreliable yet
2021-07-18 Oups forgot the DMA engine (this version with wishbone Converter)
2021-07-18 switch sdram access from Wishbone to dedicated port, seems to be more reliable
2021-07-18 SBus-OHCI driver
2021-07-24 driver update
2021-07-24 SDRAM driver now complete enough to sunlabel/newfs
2021-08-21 try to track down the issue...
2021-08-21 (optional) checksumming in SDRAM DMA, change clocking on Engine, ...
2021-08-21 move the last errored address to sbusfpga_stat ; add missing stat driver
2021-08-23 ioctl on/off switch on stats + ctrl pgm
2021-08-28 Fewer LEDs, more interrupts, replace USB VBus power chip by something that might be available..., update signals file
    [B2B.sch, blinkey.sch, sbus-to-ztex.csv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]
2021-08-28 Update more stuff to V1.2
    [B2B.sch, sbus-to-ztex.csv, sbus-to-ztex.kicad_pcb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]
2021-08-28 USB ID pin left floating
    [sbus-to-ztex.kicad_pcb, usb.sch]
2021-09-06 More prep; splits CSR includes per-device
2021-09-19 More V1.X stuff, still need to modularize the PROM. Also, why irqs other than 3 fails in Migen in V1.2 ???
    [ztex213_sbus.py]
2021-10-01 forgotten to commit extension for V1.0 with fan carrier
    [Backplate.scad, Backplate.stl]
2021-10-02 update backplate to V1.2
    [Backplate.scad]
2021-10-07 start working on some form of how-to, improve backplate for V1.2
    [Backplate.scad, Backplate.stl]
2021-10-09 add VGA222 Pmod
    [VGA222-PMOD-B.Cu.gbr, VGA222-PMOD-B.Mask.gbr, VGA222-PMOD-B.Paste.gbr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]
2021-10-09 fix irq priority handling in ohci-sbus device
2021-10-30 more improvements
    [Backplate.scad, Backplate.stl]
2021-11-13 upd backplate
    [Backplate.scad, Backplate.stl]
2021-11-13 cleanup, preliminary sdcard driver
2021-11-13 sdcard, interrupt line on sdram
2021-11-14 can't get async (interrupt-based) sdram driver to work
2021-11-17 various updates, and prom driver for sdcard
2021-11-19 better sd(ram|card) drivers
2021-12-19 Simple model of SBus retainer
    [SBus_Retainer.scad, SBus_Retainer.stl]
2022-01-26 fix sdram prom config fix, drop DMA from the sdram DMA and talk to a native SDRAM port instead
2022-01-29 improve backplate
    [Backplate.scad]
2022-01-29 preliminary i2c support via the OC I2C ctrl & betrustedio wrapper
    Now with a NetBSD driver (based on the OpenBSD one) that shows the i2c bus, and some prom support. Not tested with a device, waiting on custom Pmod.
2022-02-25 fix i2c support
2022-07-24 vmsize in MiB not KiB (thread at http://mail-index.netbsd.org/port-sparc/2022/02/27/msg002432.html)
2022-09-03 For some reason, the dkdriver needs open/close otherwise we can't mount / when booting from sdcard
2022-11-18 Fix support for USB, I2C in updated Litex & submodules
2023-09-17 thinking about a V1.3
    [B2B.sch, blinkey.sch, sbus-to-ztex.csv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]
2023-09-19 more V1.3
    [B2B.sch, BM04B-SRSS-TB-LF--SN---3DModel-STEP-56544.STEP, DM3CS-SF.step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]
2023-09-21 minor upd
    [sbus-to-ztex.kicad_pcb]
2023-10-07 missing connection (no impact, connected elsewhere)
    [B2B.sch]
